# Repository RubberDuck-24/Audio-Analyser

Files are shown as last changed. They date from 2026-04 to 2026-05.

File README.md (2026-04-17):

# Audio-Analyser

PC-controlled audio analyzer with integrated dummy load for objective testing and calibration of audio amplifiers.

## Overview

This project provides a complete measurement chain for testing audio amplifiers — measuring key parameters like THD(+N), frequency response, and noise level. It replaces subjective "does it sound right?" evaluations with quantitative, reproducible, and logged results.

Developed as a bachelor project at Ingeniørhøjskolen, Aarhus University.

## Features

- **FFT-based spectrum analysis** with live updating display
- **THD+N measurement** at 1 kHz (and across frequency)
- **Internal loopback** via integrated DAC → ADC signal path
- **Dummy load** switchable between 4 Ω and 8 Ω, rated for ≥ 200 W
- **Over-temperature protection** with automatic relay cutoff (fail-safe)
- **Data logging** to CSV/JSON with date, DUT ID, load mode and sample rate
- **PDF report generation** with test info, results and FFT plots
- **24-bit / 192 kHz** dual-channel synchronous capture

## System Architecture
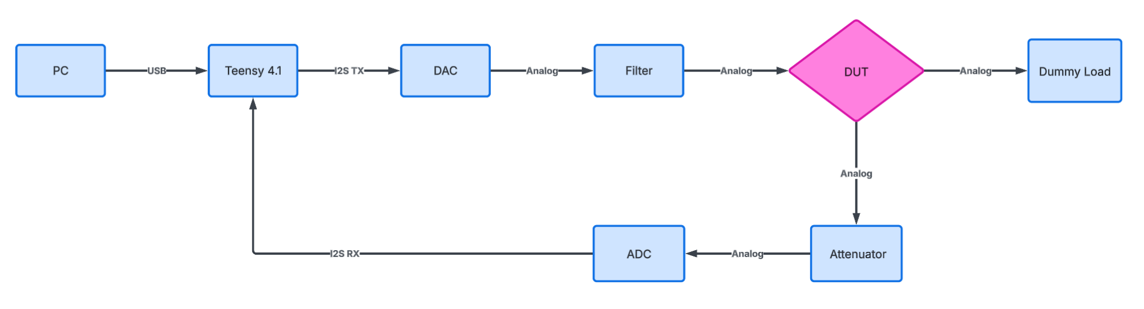
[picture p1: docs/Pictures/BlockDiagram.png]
System Architecture

The signal chain is split into two branches:
- **Generator path**: PC → Teensy → DAC → Filter → DUT
- **Measurement path**: DUT → Attenuator → ADC → Teensy → PC

## Hardware

| Component | Description |
|---|---|
| Teensy 4.1 | MCU — USB High-Speed (480 Mbit/s), hardware I2S TX/RX |
| TI PCM4222EVM | 24-bit, 2-channel delta-sigma ADC |
| Adafruit PCM5102 | 32-bit I2S DAC, line-level output (~2.1 V RMS), no external control bus needed |
| Dummy Load | 16× 2 Ω/100 W resistors, 2-branch per channel configuration, relay-switched 4 Ω / 8 Ω |

## Repository Structure

Audio-Analyser/
- docs: Documentation, reports, measurements and pictures
- firmware: Teensy 4.1 firmware (PlatformIO / Arduino framework)
- software: PC-side Python application (FFT GUI, logging, reporting)

## Measurement Standards

Audio measurements are referenced against **DS/EN IEC 60268-3:2018** — *Sound system equipment, Part 3: Amplifiers* — used as a technical reference for parameters such as THD(+N), frequency response, and load conditions.

## Author

**Christian Rasmussen**

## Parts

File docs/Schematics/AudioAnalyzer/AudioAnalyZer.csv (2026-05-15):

Reference | Qty | Value | DNP | Exclude from BOM | Exclude from Board | Footprint | Datasheet | MANUFACTURER | MAXIMUM_PACKAGE_HEIGHT | MF | MP | PARTREV | Package | Price | Purchase-URL | STANDARD | Sim.Device | Sim.Pins | SnapEDA_Link | VERIFIER
C1,C6,C7,C28,C37,C38,C39,C41,C43,C44,C45,C46,C52,C56,C57,C58,C62,C65,C69,C71,C73,C74,C81,C82,C83,C84,C86 | 27 | 100nF |  |  |  | Capacitor_SMD:C_0603_1608Metric_Pad1.08x0.95mm_HandSolder
C2,C27,C54,C55 | 4 | 22uF |  |  |  | Capacitor_SMD:C_1206_3216Metric
C3,C29 | 2 | 47uF |  |  |  | Capacitor_SMD:CP_Elec_10x10.5
C4,C5,C23,C24 | 4 | 47uF |  |  |  | Capacitor_SMD:CP_Elec_6.3x7.7
C8,C9 | 2 | 10uF |  |  |  | Capacitor_SMD:C_1206_3216Metric
C10 | 1 | 100nF |  |  |  | Capacitor_SMD:C_0805_2012Metric
C11 | 1 | 10uF |  |  |  | Capacitor_SMD:CP_Elec_8x10.5
C12,C18,C19 | 3 | 2.2uF |  |  |  | Capacitor_SMD:C_1210_3225Metric
C14,C21 | 2 | 6800pF |  |  |  | Capacitor_SMD:C_0603_1608Metric_Pad1.08x0.95mm_HandSolder
C15,C22 | 2 | 39pF |  |  |  | Capacitor_SMD:C_0603_1608Metric_Pad1.08x0.95mm_HandSolder
C16,C17 | 2 | 47uF |  |  |  | Capacitor_SMD:C_1210_3225Metric
C20,C30 | 2 | 0.1uF |  |  |  | Capacitor_SMD:C_0603_1608Metric_Pad1.08x0.95mm_HandSolder
C25 | 1 | 2.2uF |  |  |  | Capacitor_SMD:C_1210_3225Metric_Pad1.33x2.70mm_HandSolder
C31 | 1 | 2.7nF |  |  |  | Capacitor_SMD:C_0603_1608Metric
C33,C35,C49,C50 | 4 | 100pF |  |  |  | Capacitor_SMD:C_0603_1608Metric_Pad1.08x0.95mm_HandSolder
C34,C36,C40,C47,C48,C51,C64,C76,C88 | 9 | DNP |  |  |  | Capacitor_SMD:C_0603_1608Metric_Pad1.08x0.95mm_HandSolder
C42,C53 | 2 | 100uF |  |  |  | Capacitor_SMD:C_1210_3225Metric
C59 | 1 | 2.7nF |  |  |  | Capacitor_SMD:C_0603_1608Metric_Pad1.08x0.95mm_HandSolder
C60,C61 | 2 | 2.2nF |  |  |  | Capacitor_SMD:C_0603_1608Metric_Pad1.08x0.95mm_HandSolder
C63,C77,C85,C87 | 4 | 1uF |  |  |  | Capacitor_SMD:C_0603_1608Metric_Pad1.08x0.95mm_HandSolder
C66,C67 | 2 | 2.2uF |  |  |  | Capacitor_SMD:C_1206_3216Metric
C68,C70,C72,C75,C78 | 5 | 10uF |  |  |  | Capacitor_SMD:C_0805_2012Metric
C79,C80 | 2 | 10uF |  |  |  | Capacitor_Tantalum_SMD:CP_EIA-3216-18_Kemet-A
CR1,CR2,CR3,CR4,CR5,CR6,CR7,CR8 | 8 | VS-15MQ040-M3/5AT |  |  |  | VS-15MQ040-M3-5AT:CR_Q040-M3&slash_5AT_VIS | https://www.vishay.com/doc?93366
D1,D2 | 2 | S1G-13-F |  |  |  | Diode_SMD:D_SMA | https://www.diodes.com/assets/Datasheets/ds16008.pdf |  |  |  |  |  |  |  |  |  | D | 1=K 2=A
D3,D5 | 2 | B560C-13-F |  |  |  | Diode_SMD:D_SMC_Handsoldering
D4 | 1 | SMCJ58A-13-F |  |  |  | SMCJ58A-13-F:DIOM7959X250N |  | Diodes Incorporated | 2.5mm | Diodes Inc. | SMCJ58A-13-F | 2-May | DO-214 Diodes Inc. | None | https://www.snapeda.com/api/url_track_click_mouser/?unipart_id=831879&manufacturer=Diodes Inc.&part_name=SMCJ58A-13-F&search_term=smcj58a-13-f | IPC-7351B |  |  | https://www.snapeda.com/parts/SMCJ58A-13-F/Diodes+Inc./view-part/?ref=snap
D6,D7,D8,D9,D10,D11,D12,D13,D14 | 9 | LED |  |  |  | LED_SMD:LED_0603_1608Metric_Pad1.05x0.95mm_HandSolder |  |  |  |  |  |  |  |  |  |  |  | 1=K 2=A
F2 | 1 | Fuse |  |  |  | 0451002:0451Series_LTF-M
FB1,FB2 | 2 | FerriteBead |  |  |  | BLM21PG221SN1D:BEADC2012X105N
J1,J3,J4,J6 | 4 | CONBNC002 |  |  |  | CONBNC002:LINX_CONBNC002 |  |  |  | TE Connectivity | CONBNC002 |  | None | None | https://www.snapeda.com/api/url_track_click_mouser/?unipart_id=10849425&manufacturer=Linx Technologies Inc.&part_name=CONBNC002&search_term=None |  |  |  | https://www.snapeda.com/parts/CONBNC002/TE+Connectivity/view-part/?ref=snap
J2 | 1 | Barrel_Jack |  |  |  | Connector_BarrelJack:BarrelJack_CUI_PJ-063AH_Horizontal
J5 | 1 | DummyLoad |  |  |  | Connector_PinHeader_2.54mm:PinHeader_1x07_P2.54mm_Horizontal
K3,K4,K5,K6,K7,K8,K9,K10 | 8 | Relay_DPDT |  |  |  | IM06DGR:RELAY_IM06DGR
L2,L3,L5,L6 | 4 | 22uH |  |  |  | HCM1A0805V2:IND_HCM1A0805V2_EAT-L
L7 | 1 | 8.2uH |  |  |  | WE-PD_1030P:WE-PD_1030P
OSC1 | 1 | SM7745HEV |  |  |  | SM7745HEV:SM77H_PLT | SM7745HEV-50.0M
Q1,Q2,Q3,Q4,Q5,Q6,Q7,Q8 | 8 | NX3008NBKW |  |  |  | NX3008NBKW:SC-70_SOT323_NEX | NX3008NBKW
R1,R3,R20,R22,R34,R35,R36,R37 | 8 | 33.6k |  |  |  | Resistor_SMD:R_0603_1608Metric_Pad0.98x0.95mm_HandSolder
R2 | 1 | 4.7 |  |  |  | Resistor_SMD:R_1206_3216Metric_Pad1.30x1.75mm_HandSolder
R4,R10 | 2 | 84.5 |  |  |  | Resistor_SMD:R_0603_1608Metric_Pad0.98x0.95mm_HandSolder
R5,R9 | 2 | 523k |  |  |  | Resistor_SMD:R_0805_2012Metric_Pad1.20x1.40mm_HandSolder
R6,R12 | 2 | 13k |  |  |  | Resistor_SMD:R_0603_1608Metric_Pad0.98x0.95mm_HandSolder
R7 | 1 | 53.6k |  |  |  | Resistor_SMD:R_0603_1608Metric_Pad0.98x0.95mm_HandSolder
R8,R14 | 2 | 10.2k |  |  |  | Resistor_SMD:R_0603_1608Metric_Pad0.98x0.95mm_HandSolder
R11,R19 | 2 | 162k |  |  |  | Resistor_SMD:R_0603_1608Metric_Pad0.98x0.95mm_HandSolder
R13 | 1 | 143k |  |  |  | Resistor_SMD:R_0603_1608Metric_Pad0.98x0.95mm_HandSolder
R15,R16,R43,R44 | 4 | 40.2 |  |  |  | Resistor_SMD:R_0603_1608Metric_Pad0.98x0.95mm_HandSolder
R17,R18,R45,R46,R77 | 5 | 0 |  |  |  | Resistor_SMD:R_0603_1608Metric_Pad0.98x0.95mm_HandSolder
R21 | 1 | 0/DNP |  |  |  | Resistor_SMD:R_0603_1608Metric_Pad0.98x0.95mm_HandSolder
R23,R24,R38,R39 | 4 | 16.8k |  |  |  | Resistor_SMD:R_0603_1608Metric_Pad0.98x0.95mm_HandSolder
R25,R26,R41,R42 | 4 | 2.7k |  |  |  | Resistor_SMD:R_0603_1608Metric_Pad0.98x0.95mm_HandSolder
R27,R28,R29,R31,R32,R33,R47,R49,R50,R51,R52,R53,R54,R55,R56,R57,R58,R59,R60,R61,R62,R63,R67,R70,R78,R79,R82,R83 | 28 | 10k |  |  |  | Resistor_SMD:R_0603_1608Metric_Pad0.98x0.95mm_HandSolder
R30,R40 | 2 | 1k |  |  |  | Resistor_SMD:R_0603_1608Metric_Pad0.98x0.95mm_HandSolder
R48 | 1 | 33 |  |  |  | Resistor_SMD:R_0603_1608Metric_Pad0.98x0.95mm_HandSolder
R64,R65 | 2 | 470 |  |  |  | Resistor_SMD:R_0603_1608Metric_Pad0.98x0.95mm_HandSolder
R66,R69,R80,R81 | 4 | 100 |  |  |  | Resistor_SMD:R_0603_1608Metric_Pad0.98x0.95mm_HandSolder
R68 | 1 | 0 |  |  |  | Resistor_SMD:R_1206_3216Metric_Pad1.30x1.75mm_HandSolder
R71,R72,R73 | 3 | 47 |  |  |  | Resistor_SMD:R_0603_1608Metric_Pad0.98x0.95mm_HandSolder
R74 | 1 | 240 |  |  |  | Resistor_SMD:R_0603_1608Metric_Pad0.98x0.95mm_HandSolder
R75 | 1 | 200 |  |  |  | Resistor_SMD:R_0603_1608Metric_Pad0.98x0.95mm_HandSolder
R76 | 1 | 324 |  |  |  | Resistor_SMD:R_0603_1608Metric_Pad0.98x0.95mm_HandSolder
R84 | 1 | 100k |  |  |  | Resistor_SMD:R_1206_3216Metric_Pad1.30x1.75mm_HandSolder
R85 | 1 | 5.6k |  |  |  | Resistor_SMD:R_0603_1608Metric_Pad0.98x0.95mm_HandSolder
R86 | 1 | 20k |  |  |  | Resistor_SMD:R_0603_1608Metric_Pad0.98x0.95mm_HandSolder
R87 | 1 | 3.9k |  |  |  | Resistor_SMD:R_0603_1608Metric_Pad0.98x0.95mm_HandSolder
R88,R91 | 2 | 2.4k |  |  |  | Resistor_SMD:R_0603_1608Metric_Pad0.98x0.95mm_HandSolder
R89,R90 | 2 | 27k |  |  |  | Resistor_SMD:R_0603_1608Metric_Pad0.98x0.95mm_HandSolder
R92 | 1 | 2.2k |  |  |  | Resistor_SMD:R_0603_1608Metric_Pad0.98x0.95mm_HandSolder
RN3 | 1 | 100 |  |  |  | EXB-38V103JV:RESCAXS80P320X160X60-8N
S1 | 1 | B3F-1000 |  |  |  | B3F-1000:SW_B3F-1000 |  |  |  | Omron | B3F1000 |  | None | None |  |  |  |  | https://www.snapeda.com/parts/B3F1000/Omron/view-part/?ref=snap
U1 | 1 | PCM4222PFBR |  |  |  | PCM4222PFBR:PFB48-M | https://www.ti.com/lit/gpn/pcm4222
U2 | 1 | PCM5102A |  |  |  | Package_SO:TSSOP-20_4.4x6.5mm_P0.65mm | https://www.ti.com/lit/ds/symlink/pcm5102a.pdf
U3 | 1 | DEV-16771 |  |  |  | DEV-16771:MODULE_DEV-16771 |  | SparkFun Electronics | 4.07mm | SparkFun Electronics | DEV-16771 | 4.1 | None | None |  | Manufacturer recommendations |  |  | https://www.snapeda.com/parts/DEV-16771/SparkFun/view-part/?ref=snap
U4,U7 | 2 | OPA1632D |  |  |  | OPA1632D:SOIC127P599X175-8N |  |  |  | Texas Instruments | OPA1632D |  | SOIC-8 Texas Instruments | None |  |  |  |  | https://www.snapeda.com/parts/OPA1632D/Texas+Instruments/view-part/?ref=snap
U5,U6 | 2 | OPA277UA |  |  |  | OPA277UA:SOIC127P599X175-8N |  | Texas Instruments | 1.75 mm | Texas Instruments | OPA277UA | Feb-19 | SOIC-8 Texas Instruments | None |  | IPC 7351B |  |  | https://www.snapeda.com/parts/OPA277UA/Texas+Instruments/view-part/?ref=snap
U8,U11 | 2 | TPS54360BDDAR |  |  |  | TPS54360BDDAR:U_DDA_TEX-M | https://www.ti.com/lit/gpn/tps54360b
U9 | 1 | REG1117-3.3G4 |  |  |  | REG1117-3.3G4:SOT230P700X180-4N |  |  |  | Texas Instruments | REG1117-3.3G4 |  | SOT-223-4 Texas Instruments | None |  |  |  |  | https://www.snapeda.com/parts/REG1117-3.3G4/Texas+Instruments/view-part/?ref=snap
U10 | 1 | LM317_TO-252 |  |  |  | Package_TO_SOT_SMD:TO-252-2 | http://www.ti.com/lit/ds/snvs774n/snvs774n.pdf
U12 | 1 | ADR4525BRZ |  |  |  | ADR4525BRZ:SOIC127P600X175-8N |  | Analog Devices | 1.75mm | Analog Devices | ADR4525BRZ | G | SOIC-8 Analog Devices | None |  | IPC-7351B |  |  | https://www.snapeda.com/parts/ADR4525BRZ/Analog+Devices/view-part/?ref=snap
U13 | 1 | DKA15C-15 |  |  |  | DKA15C:DKA15C

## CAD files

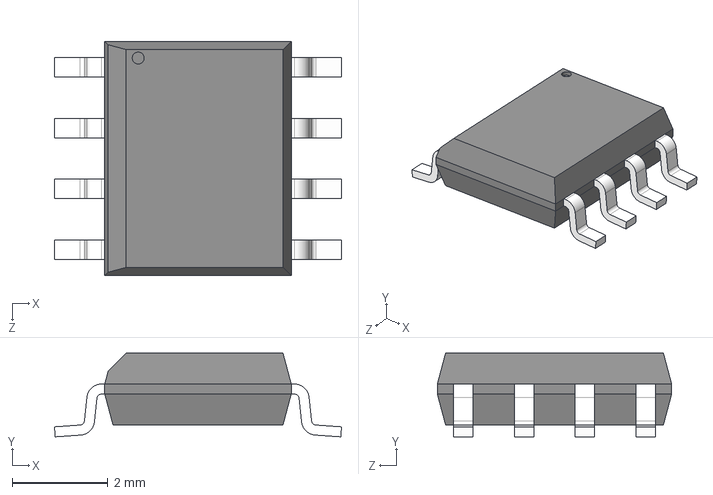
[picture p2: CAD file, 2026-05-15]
docs/Parts/ADR4525BRZ/ADR4525BRZ.step
6.00 x 1.75 x 4.90 mm

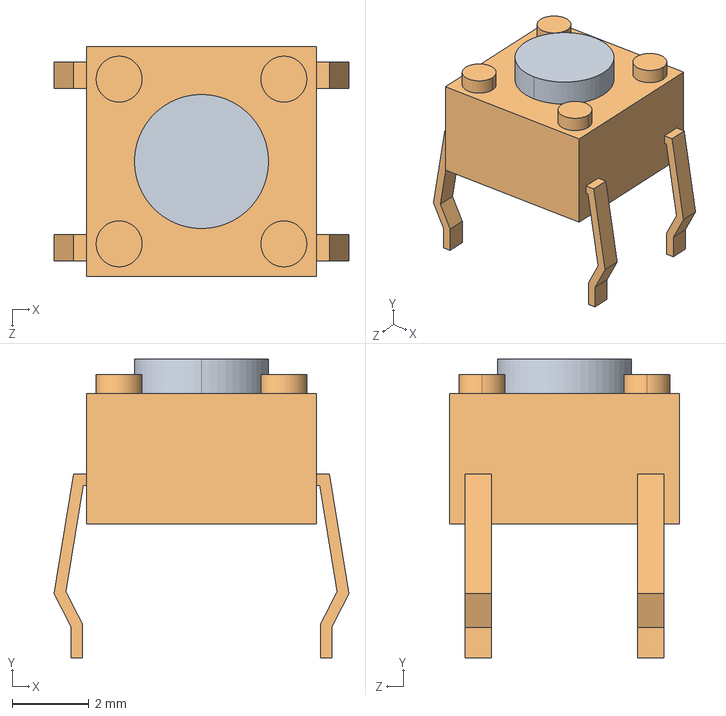
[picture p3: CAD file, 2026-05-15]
docs/Parts/B3F-1000/B3F-1000.step
7.70 x 7.80 x 6.00 mm
B3F_1000_BUTTON
B3F_1000_BASE

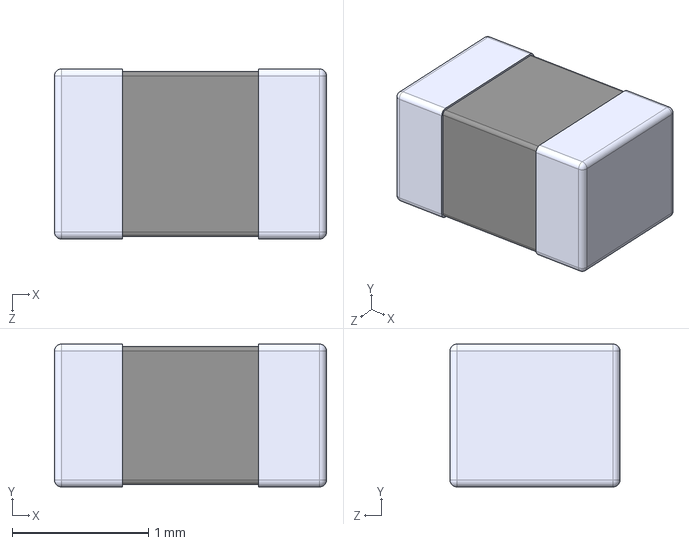
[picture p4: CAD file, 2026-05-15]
docs/Parts/BLM21PG221SN1D/BLM21PG221SN1D.step
2.00 x 1.05 x 1.25 mm

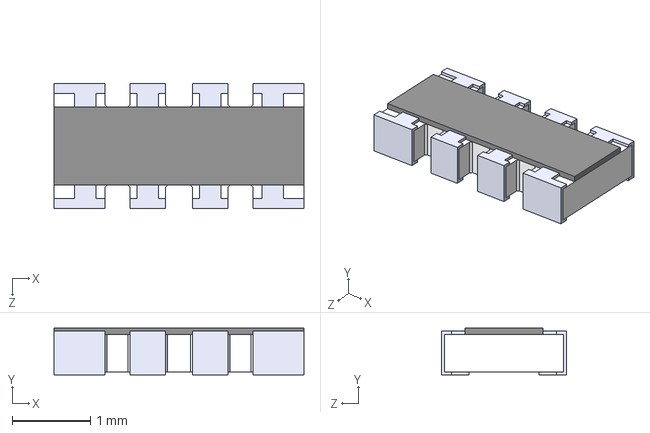
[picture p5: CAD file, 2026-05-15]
docs/Parts/EXB-38V103JV/EXB-38V103JV.step
3.20 x 0.6 x 1.60 mm

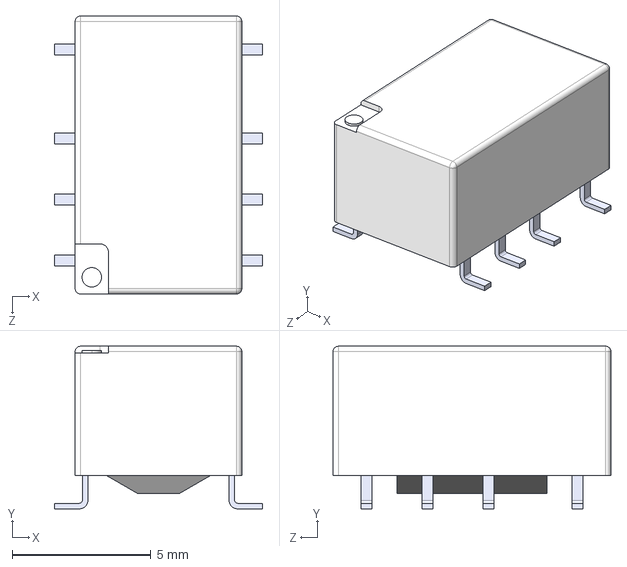
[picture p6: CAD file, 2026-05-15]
docs/Parts/IM06DGR/IM06DGR.step
7.50 x 5.85 x 10.0 mm

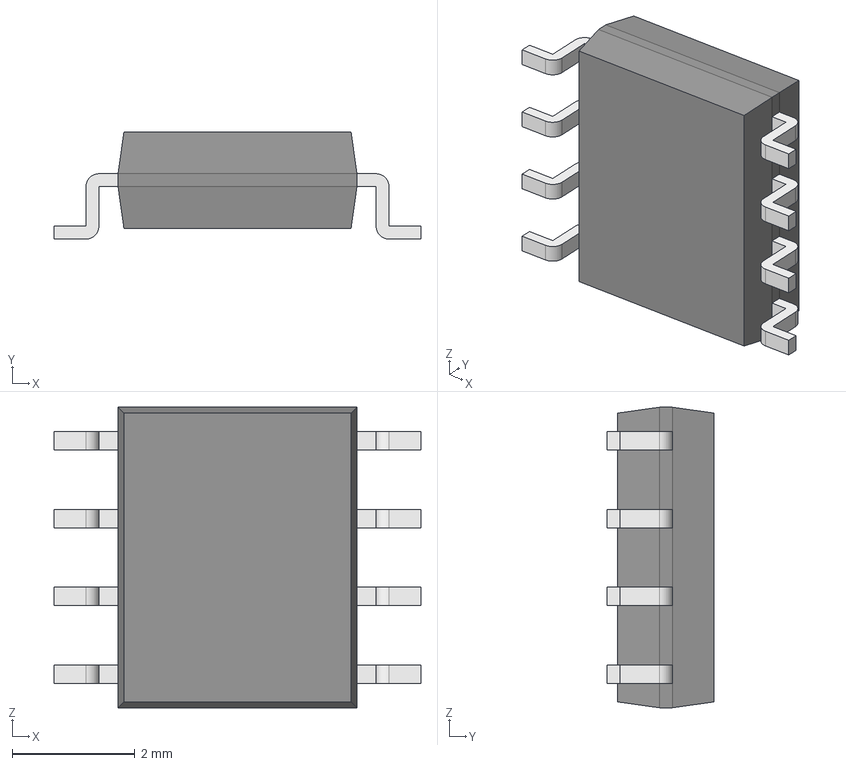
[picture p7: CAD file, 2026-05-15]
docs/Parts/OPA1632D/OPA1632D.step
5.99 x 1.75 x 4.91 mm
Body001 (Mirror #1) x 4
XY-plane x 12
X-axis x 12

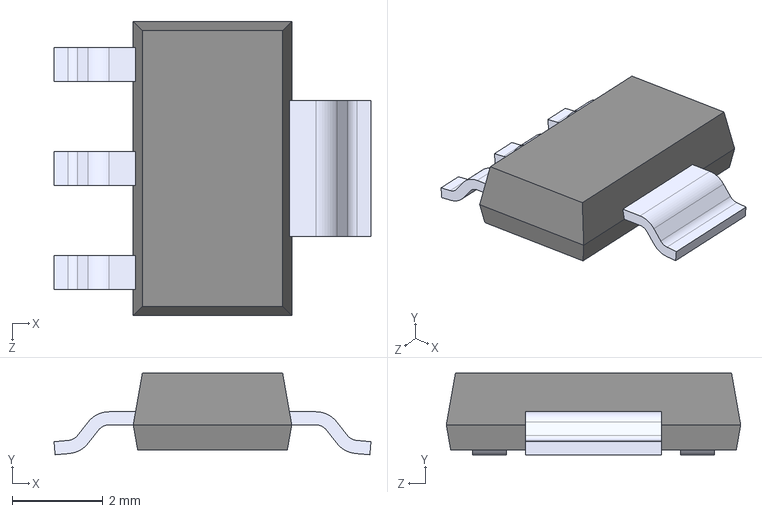
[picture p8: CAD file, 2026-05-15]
docs/Parts/REG1117-3.3G4/REG1117-3.3G4.step
7.00 x 1.80 x 6.50 mm

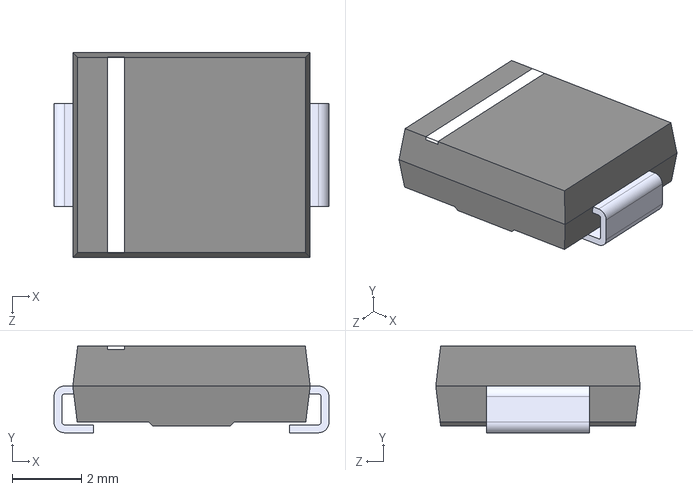
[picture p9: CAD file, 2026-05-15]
docs/Parts/SMCJ58A-13-F/SMCJ58A-13-F.step
7.94 x 2.50 x 5.91 mm

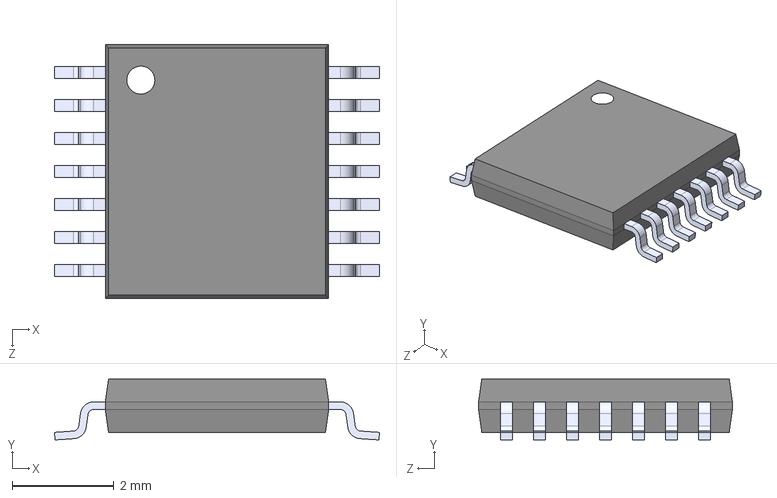
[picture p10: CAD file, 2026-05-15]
docs/Parts/SN74LVC74APW/SN74LVC74APW.step
6.40 x 1.20 x 5.00 mm

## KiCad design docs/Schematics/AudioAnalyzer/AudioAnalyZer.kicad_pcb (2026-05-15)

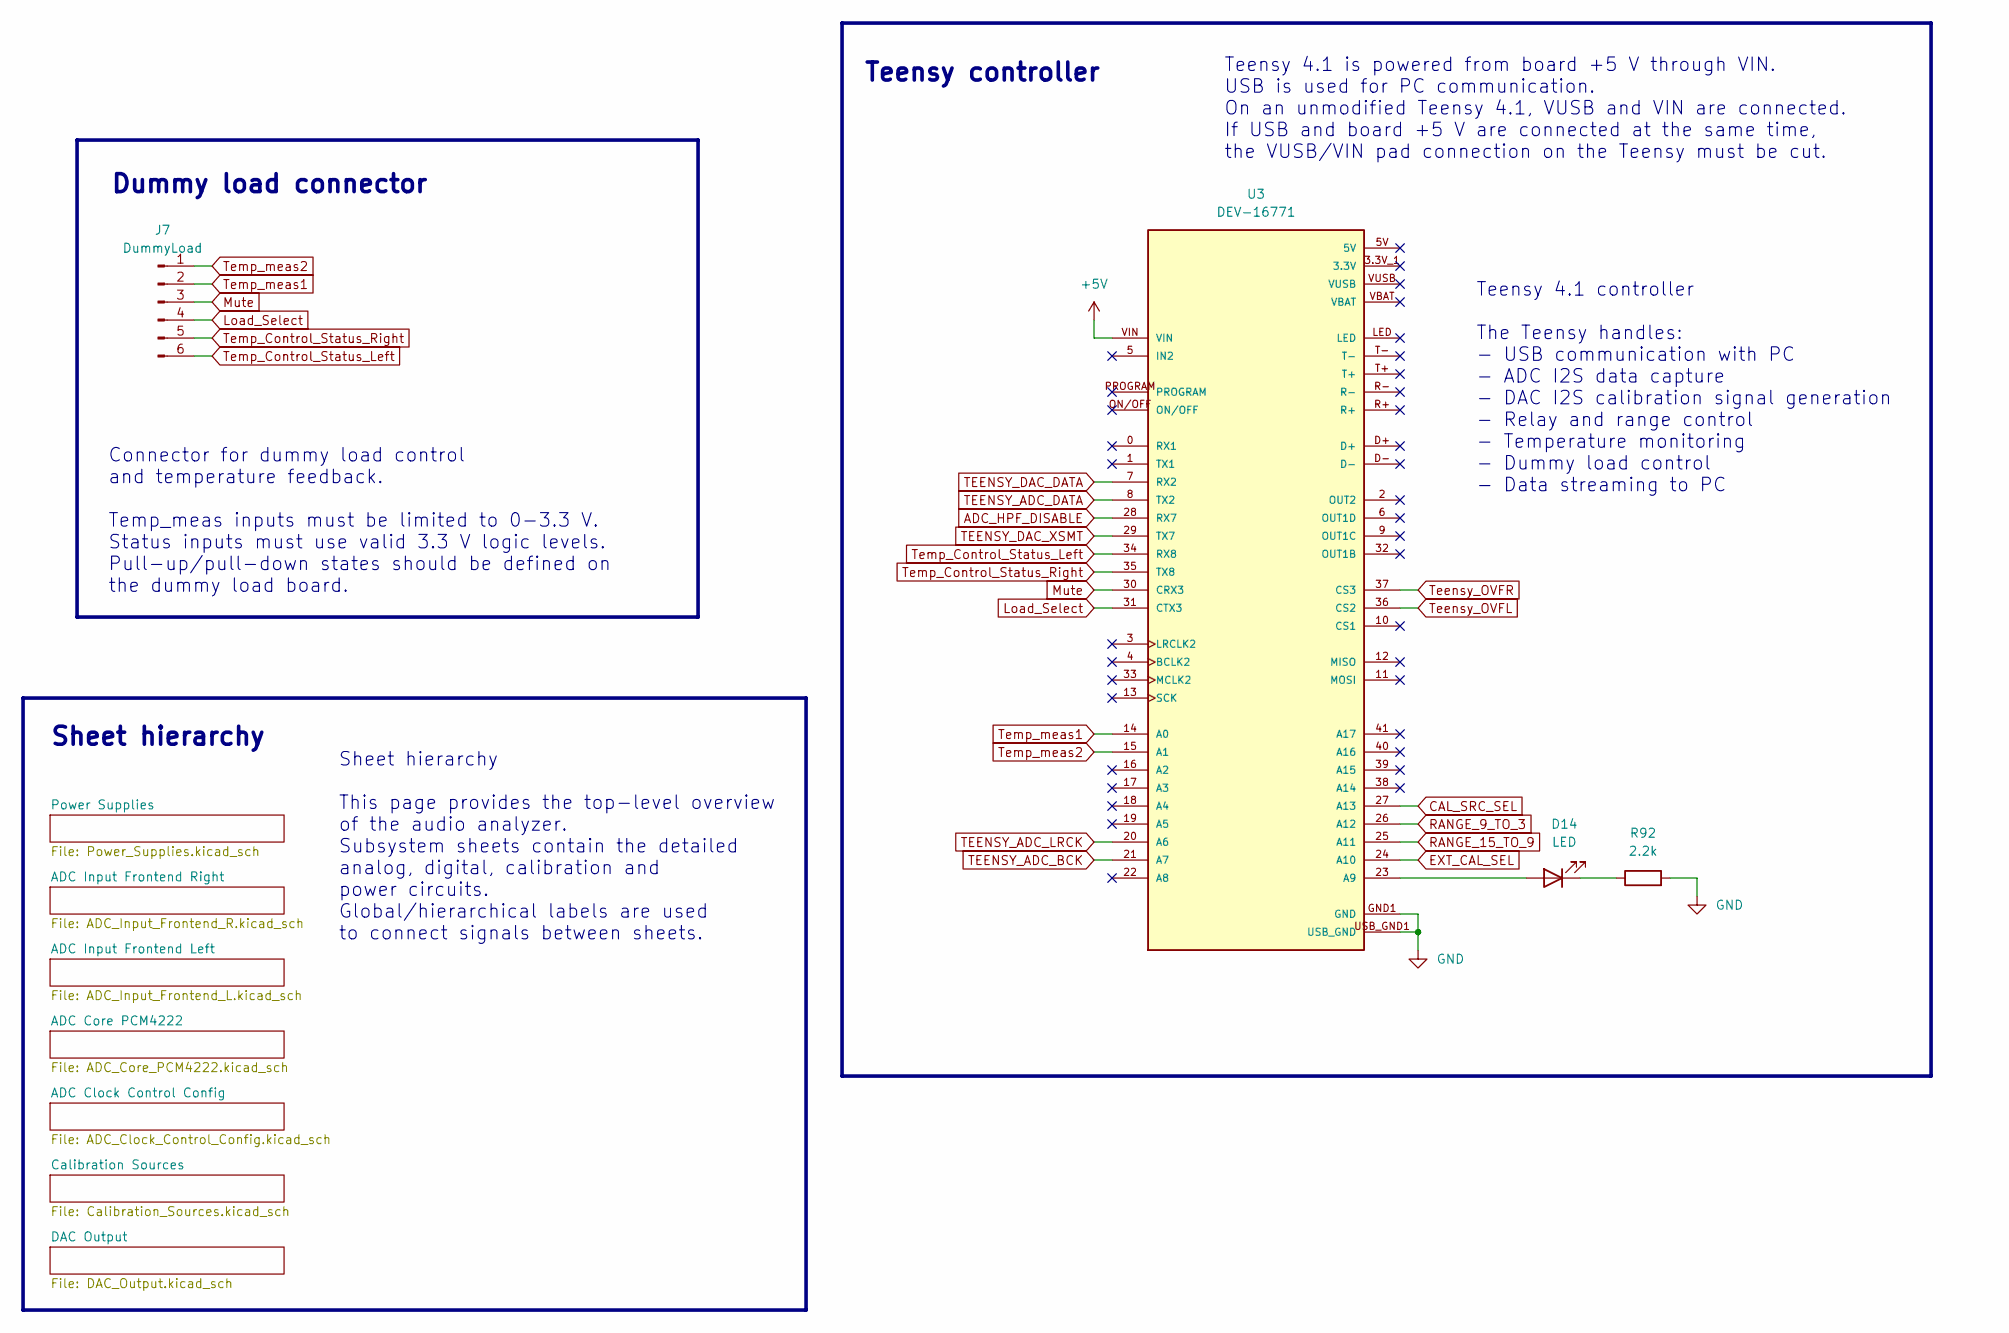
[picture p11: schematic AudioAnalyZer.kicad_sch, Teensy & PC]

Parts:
D14: LED; LED_0603_1608Metric_Pad1.05x0.95mm_HandSolder
J7: DummyLoad; PinHeader_1x06_P2.54mm_Horizontal
R92: 2.2k; R_0603_1608Metric_Pad0.98x0.95mm_HandSolder
U3: DEV-16771; MODULE_DEV-16771; PARTREV 4.1

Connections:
+5V: U3.VIN; also elsewhere on the board
ADC_HPF_DISABLE: U3.28 (RX7); also elsewhere on the board
CAL_SRC_SEL: U3.27 (A13); also elsewhere on the board
EXT_CAL_SEL: U3.24 (A10); also elsewhere on the board
GND: R92.2, U3.GND1 (GND), U3.GND2 (GND), U3.GND3 (GND), U3.GND4 (GND), U3.GND5 (GND), U3.USB_GND1 (USB_GND), U3.USB_GND2 (USB_GND); also elsewhere on the board
Load_Select: J7.4, U3.31 (CTX3)
Mute: J7.3, U3.30 (CRX3)
unnamed: D14.2 (A), U3.23 (A9)
unnamed: D14.1 (K), R92.1
RANGE_9_TO_3: U3.26 (A12); also elsewhere on the board
RANGE_15_TO_9: U3.25 (A11); also elsewhere on the board
TEENSY_ADC_BCK: U3.21 (A7); also elsewhere on the board
TEENSY_ADC_DATA: U3.8 (TX2); also elsewhere on the board
TEENSY_ADC_LRCK: U3.20 (A6); also elsewhere on the board
TEENSY_DAC_DATA: U3.7 (RX2); also elsewhere on the board
TEENSY_DAC_XSMT: U3.29 (TX7); also elsewhere on the board
Teensy_OVFL: U3.36 (CS2); also elsewhere on the board
Teensy_OVFR: U3.37 (CS3); also elsewhere on the board
Temp_Control_Status_Left: J7.6, U3.34 (RX8)
Temp_Control_Status_Right: J7.5, U3.35 (TX8)
Temp_meas1: J7.2, U3.14 (A0)
Temp_meas2: J7.1, U3.15 (A1)

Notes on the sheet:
Teensy controller
Teensy 4.1 controller The Teensy handles: - USB communication with PC - ADC I2S data capture - DAC I2S calibration signal generation - Relay and range control - Temperature monitoring - Dummy load control - Data streaming to PC
Teensy 4.1 is powered from board +5 V through VIN. USB is used for PC communication. On an unmodified Teensy 4.1, VUSB and VIN are connected. If USB and board +5 V are connected at the same time, the VUSB/VIN pad connection on the Teensy must be cut.
Sheet hierarchy This page provides the top-level overview of the audio analyzer. Subsystem sheets contain the detailed analog, digital, calibration and power circuits. Global/hierarchical labels are used to connect signals between sheets.
Connector for dummy load control and temperature feedback. Temp_meas inputs must be limited to 0-3.3 V. Status inputs must use valid 3.3 V logic levels. Pull-up/pull-down states should be defined on the dummy load board.
Dummy load connector
Sheet hierarchy

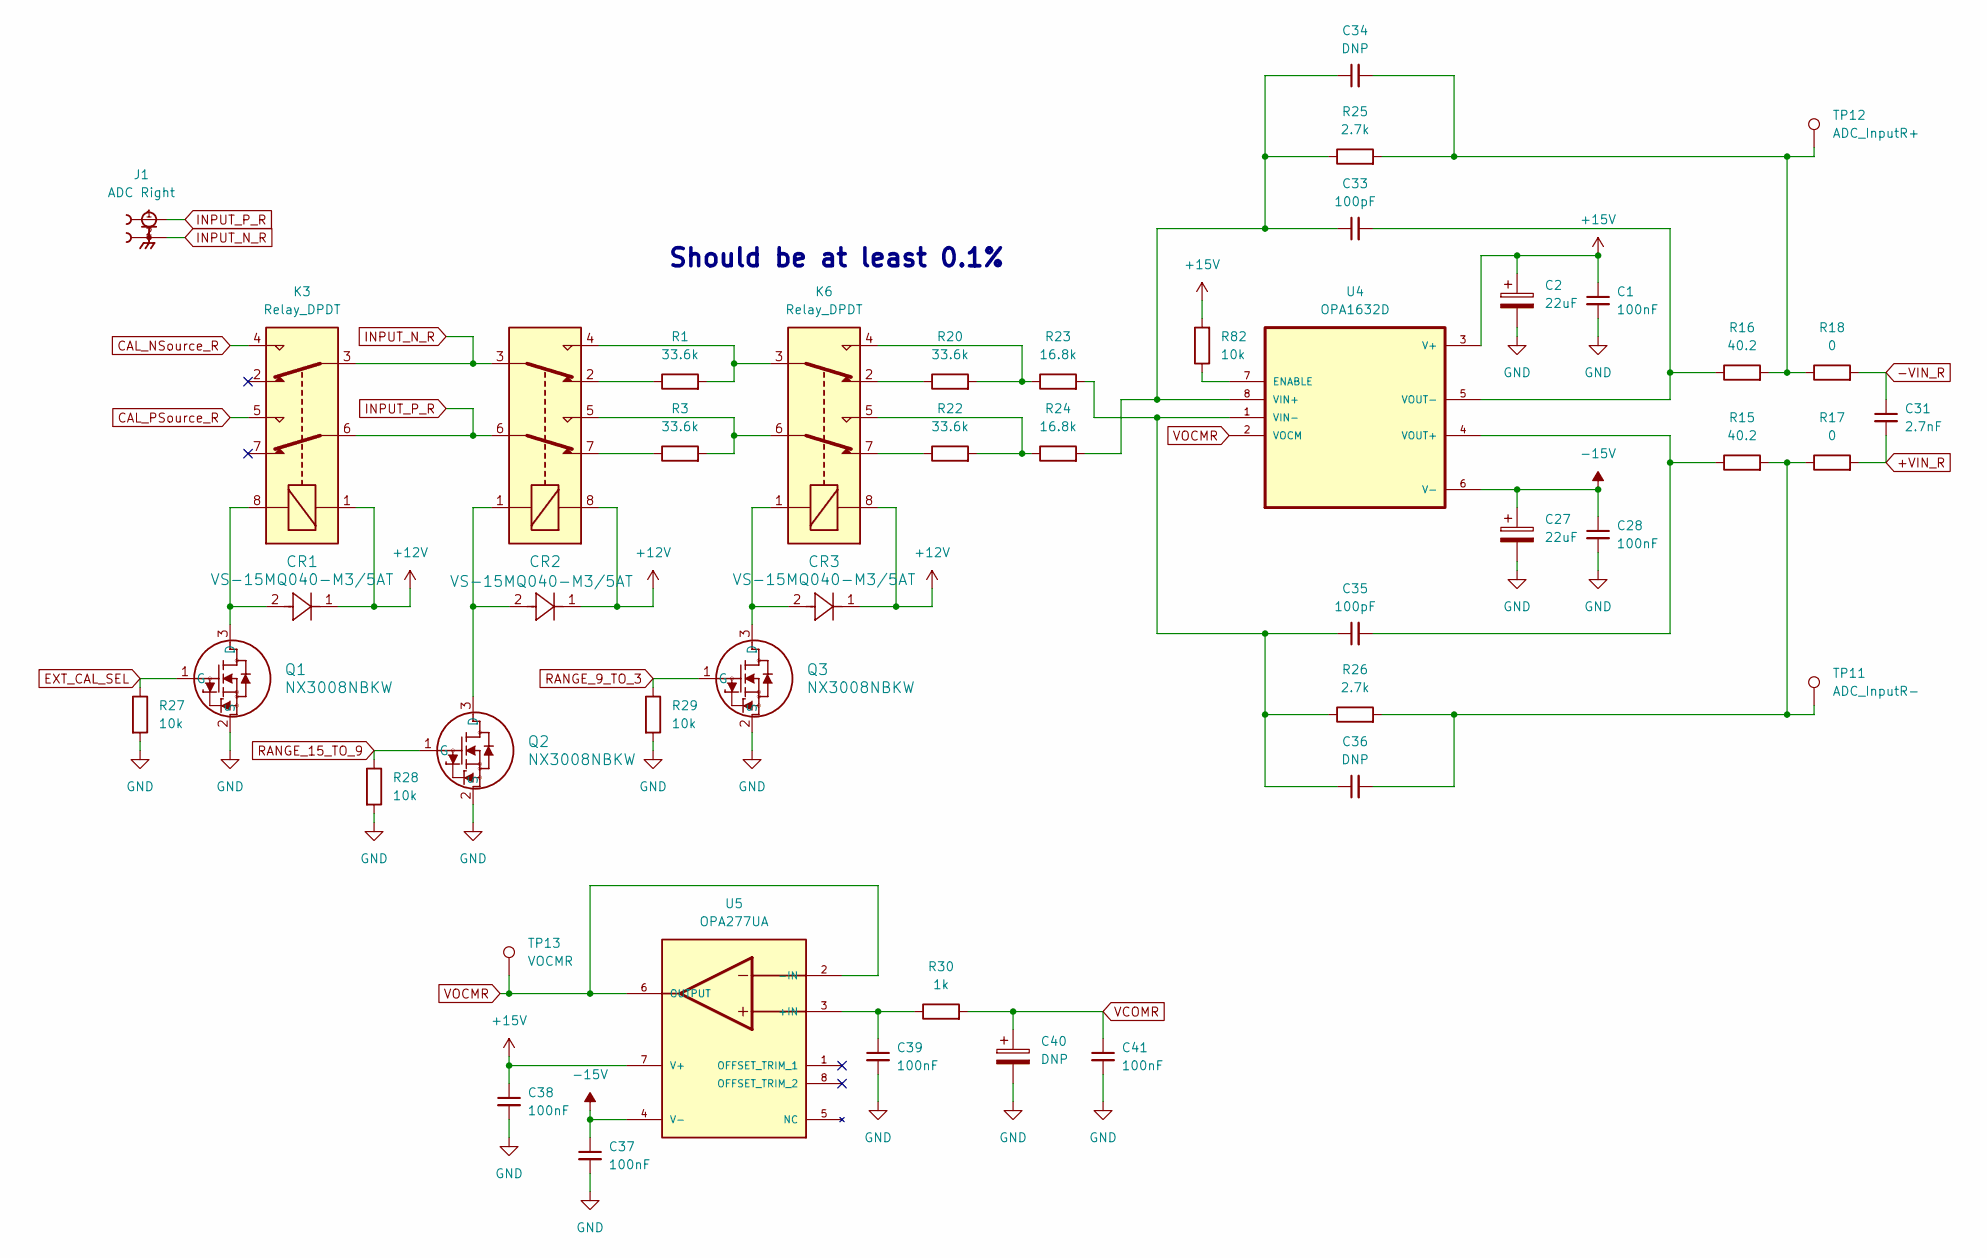
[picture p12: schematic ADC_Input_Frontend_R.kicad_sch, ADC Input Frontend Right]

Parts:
C1, C28, C37, C38, C39, C41: 100nF; C_0603_1608Metric_Pad1.08x0.95mm_HandSolder
C2, C27: 22uF; C_1206_3216Metric
C31: 2.7nF; C_0603_1608Metric
C33, C35: 100pF; C_0603_1608Metric_Pad1.08x0.95mm_HandSolder
C34, C36, C40: DNP; C_0603_1608Metric_Pad1.08x0.95mm_HandSolder
CR1, CR2, CR3: VS-15MQ040-M3/5AT; CR_Q040-M3&slash_5AT_VIS
J1: ADC Right; LINX_CONBNC002
K3, K5, K6: Relay_DPDT; RELAY_IM06DGR
Q1, Q2, Q3: NX3008NBKW; SC-70_SOT323_NEX
R1, R3, R20, R22: 33.6k; R_0603_1608Metric_Pad0.98x0.95mm_HandSolder
R15, R16: 40.2; R_0603_1608Metric_Pad0.98x0.95mm_HandSolder
R17, R18: 0; R_0603_1608Metric_Pad0.98x0.95mm_HandSolder
R23, R24: 16.8k; R_0603_1608Metric_Pad0.98x0.95mm_HandSolder
R25, R26: 2.7k; R_0603_1608Metric_Pad0.98x0.95mm_HandSolder
R27, R28, R29, R82: 10k; R_0603_1608Metric_Pad0.98x0.95mm_HandSolder
R30: 1k; R_0603_1608Metric_Pad0.98x0.95mm_HandSolder
TP11: ADC_InputR-; TestPoint_Pad_D1.5mm
TP12: ADC_InputR+; TestPoint_Pad_D1.5mm
TP13: VOCMR; TestPoint_Pad_D1.5mm
U4: OPA1632D; SOIC127P599X175-8N
U5: OPA277UA; SOIC127P599X175-8N; PARTREV 02/2019

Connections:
+12V: CR1.1, CR2.1, CR3.1, K3.1, K5.8, K6.8; also elsewhere on the board
+15V: C1.1, C2.1, C38.1, R82.2, U4.3 (V+), U5.7 (V+); also elsewhere on the board
+VIN_R: C31.2, R17.2; also elsewhere on the board
-15V: C27.1, C28.1, C37.1, U4.6 (V-), U5.4 (V-); also elsewhere on the board
-VIN_R: C31.1, R18.2; also elsewhere on the board
CAL_NSource_R: K3.4; also elsewhere on the board
CAL_PSource_R: K3.5; also elsewhere on the board
EXT_CAL_SEL: Q1.1 (G), R27.1; also elsewhere on the board
GND: C1.2, C2.2, C27.2, C28.2, C37.2, C38.2, C39.2, C40.2, C41.2, Q1.2 (S), Q2.2 (S), Q3.2 (S), R27.2, R28.2, R29.2; also elsewhere on the board
INPUT_N_R: J1.2, J1.S1, J1.S2, K3.3, K5.3
INPUT_P_R: J1.1, K3.6, K5.6
unnamed: C34.2, R16.2, R18.1, R25.2, TP12.1 (1_1)
unnamed: C36.2, R15.2, R17.1, R26.2, TP11.1 (1_1)
unnamed: K5.2, R1.1
unnamed: K5.4, K6.3, R1.2
unnamed: K5.5, K6.6, R3.2
unnamed: K5.7, R3.1
unnamed: K6.2, R20.1
unnamed: K6.4, R20.2, R23.1
unnamed: K6.5, R22.2, R24.1
unnamed: K6.7, R22.1
unnamed: CR1.2, K3.8, Q1.3 (D)
unnamed: CR2.2, K5.1, Q2.3 (D)
unnamed: CR3.2, K6.1, Q3.3 (D)
unnamed: R82.1, U4.7 (ENABLE)
unnamed: C33.1, C34.1, R24.2, R25.1, U4.8 (VIN+)
unnamed: C35.1, C36.1, R23.2, R26.1, U4.1 (VIN-)
unnamed: C35.2, R15.1, U4.4 (VOUT+)
unnamed: C33.2, R16.1, U4.5 (VOUT-)
unnamed: C39.1, R30.1, U5.3 (+IN)
RANGE_9_TO_3: Q3.1 (G), R29.1; also elsewhere on the board
RANGE_15_TO_9: Q2.1 (G), R28.1; also elsewhere on the board
VCOMR: C40.1, C41.1, R30.2; also elsewhere on the board
VOCMR: TP13.1 (1_1), U4.2 (VOCM), U5.2 (-IN), U5.6 (OUTPUT)

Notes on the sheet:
Should be at least 0.1%

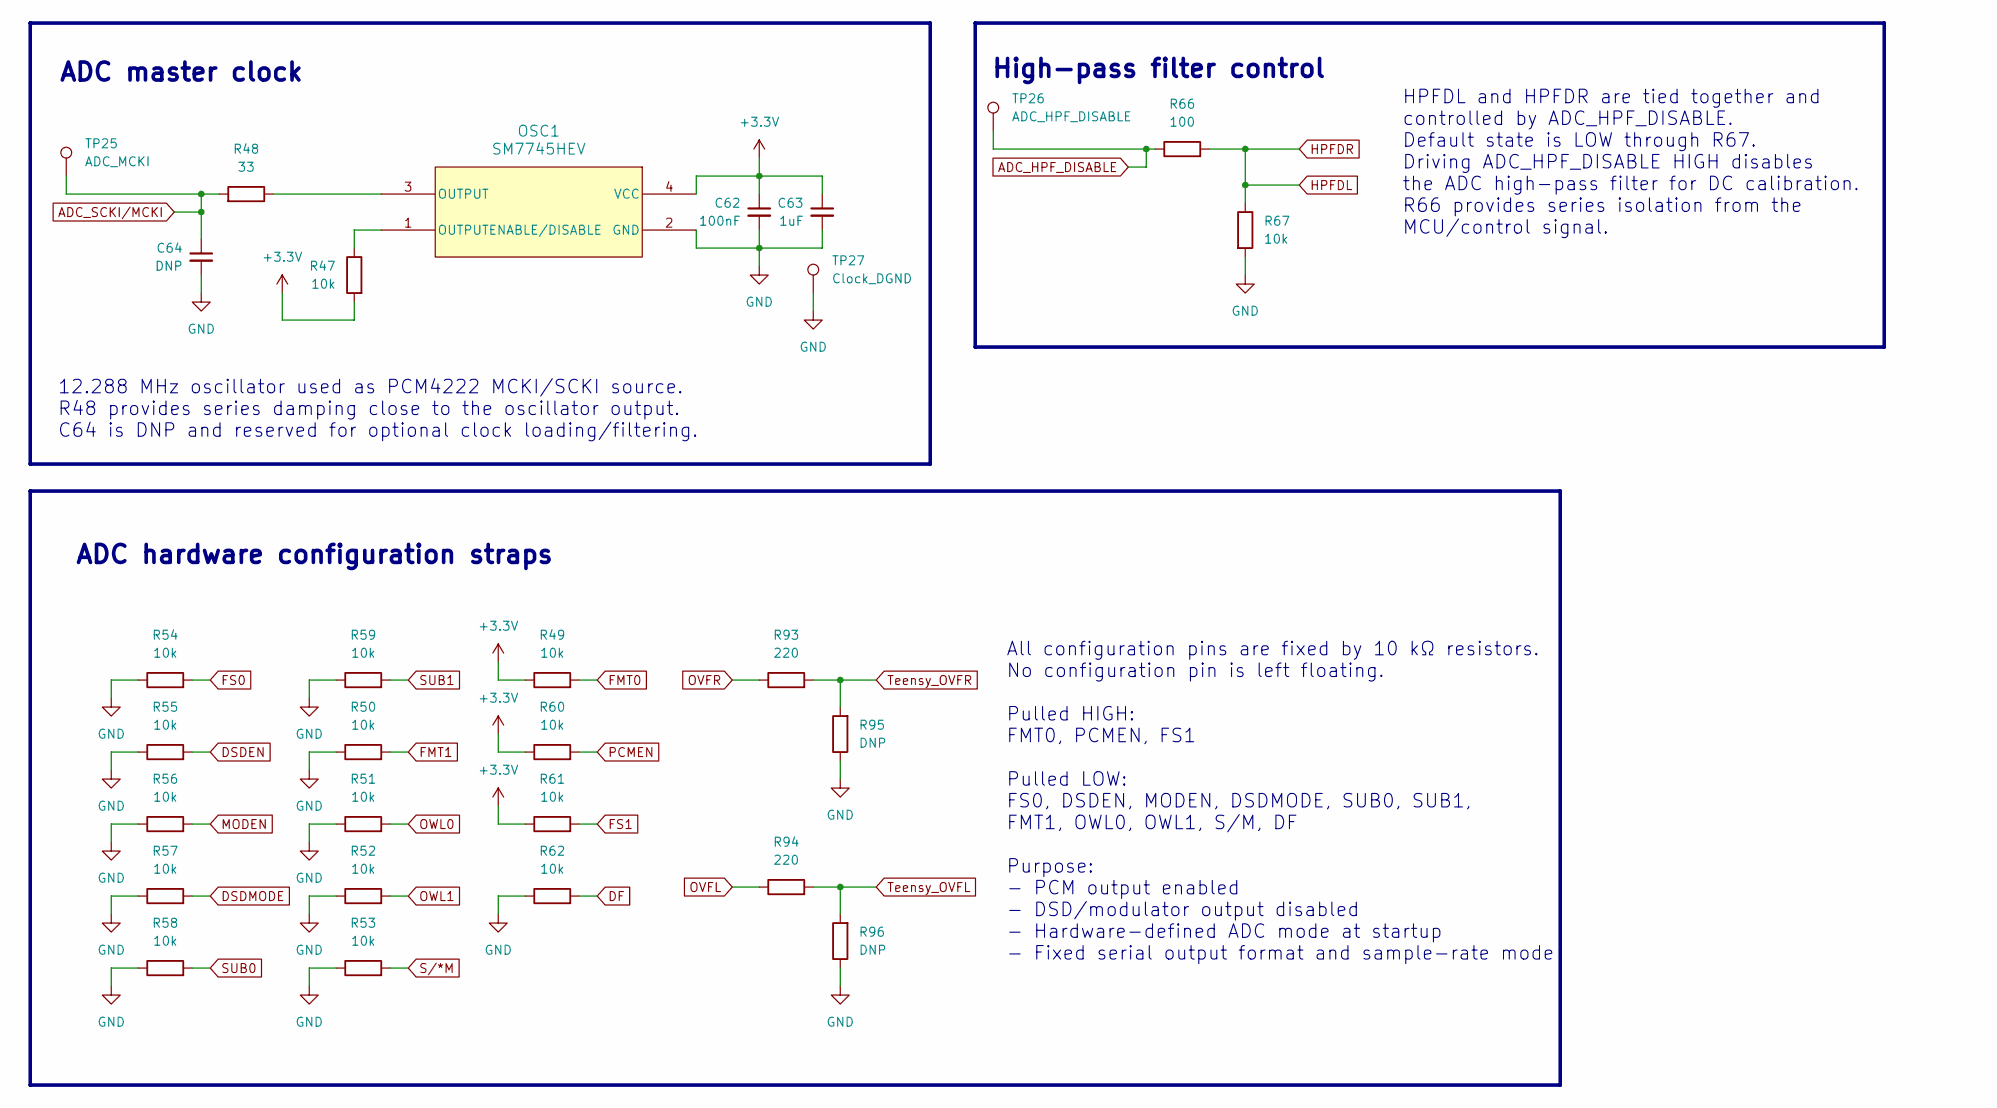
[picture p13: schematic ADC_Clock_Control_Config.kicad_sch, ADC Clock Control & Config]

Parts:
C62: 100nF; C_0603_1608Metric_Pad1.08x0.95mm_HandSolder
C63: 1uF; C_0603_1608Metric_Pad1.08x0.95mm_HandSolder
C64: DNP; C_0603_1608Metric_Pad1.08x0.95mm_HandSolder
OSC1: SM7745HEV; SM77H_PLT
R47, R49, R50, R51, R52, R53, R54, R55, R56, R57, R58, R59, R60, R61, R62, R67: 10k; R_0603_1608Metric_Pad0.98x0.95mm_HandSolder
R48: 33; R_0603_1608Metric_Pad0.98x0.95mm_HandSolder
R66: 100; R_0603_1608Metric_Pad0.98x0.95mm_HandSolder
R93, R94: 220; R_0603_1608Metric_Pad0.98x0.95mm_HandSolder
R95, R96: DNP; R_0603_1608Metric_Pad0.98x0.95mm_HandSolder
TP25: ADC_MCKI; TestPoint_Pad_D1.5mm
TP26: ADC_HPF_DISABLE; TestPoint_Pad_D1.5mm
TP27: Clock_DGND; TestPoint_Pad_D1.5mm

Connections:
+3.3V: C62.1, C63.1, OSC1.4 (VCC), R47.2, R49.1, R60.1, R61.1; also elsewhere on the board
ADC_HPF_DISABLE: R66.1, TP26.1 (1_1); also elsewhere on the board
ADC_SCKI/MCKI: C64.1, R48.2, TP25.1 (1_1); also elsewhere on the board
DF: R62.2; also elsewhere on the board
DSDEN: R55.2; also elsewhere on the board
DSDMODE: R57.2; also elsewhere on the board
FMT0: R49.2; also elsewhere on the board
FMT1: R50.2; also elsewhere on the board
FS0: R54.2; also elsewhere on the board
FS1: R61.2; also elsewhere on the board
GND: C62.2, C63.2, C64.2, OSC1.2 (GND), R50.1, R51.1, R52.1, R53.1, R54.1, R55.1, R56.1, R57.1, R58.1, R59.1, R62.1, R67.2, R95.1, R96.1, TP27.1 (1_1); also elsewhere on the board
HPFDL: R66.2, R67.1; also elsewhere on the board
MODEN: R56.2; also elsewhere on the board
unnamed: OSC1.3 (OUTPUT), R48.1
unnamed: OSC1.1 (OUTPUTENABLE/DISABLE), R47.1
OVFL: R94.1; also elsewhere on the board
OVFR: R93.1; also elsewhere on the board
OWL0: R51.2; also elsewhere on the board
OWL1: R52.2; also elsewhere on the board
PCMEN: R60.2; also elsewhere on the board
SUB0: R58.2; also elsewhere on the board
SUB1: R59.2; also elsewhere on the board
S/*M: R53.2; also elsewhere on the board
Teensy_OVFL: R94.2, R96.2; also elsewhere on the board
Teensy_OVFR: R93.2, R95.2; also elsewhere on the board

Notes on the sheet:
All configuration pins are fixed by 10 kΩ resistors. No configuration pin is left floating. Pulled HIGH: FMT0, PCMEN, FS1 Pulled LOW: FS0, DSDEN, MODEN, DSDMODE, SUB0, SUB1, FMT1, OWL0, OWL1, S/M, DF Purpose: - PCM output enabled - DSD/modulator output disabled - Hardware-defined ADC mode at startu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
ADC master clock
12.288 MHz oscillator used as PCM4222 MCKI/SCKI source. R48 provides series damping close to the oscillator output. C64 is DNP and reserved for optional clock loading/filtering.
ADC hardware configuration straps
High-pass filter control
HPFDL and HPFDR are tied together and controlled by ADC_HPF_DISABLE. Default state is LOW through R67. Driving ADC_HPF_DISABLE HIGH disables the ADC high-pass filter for DC calibration. R66 provides series isolation from the MCU/control signal.

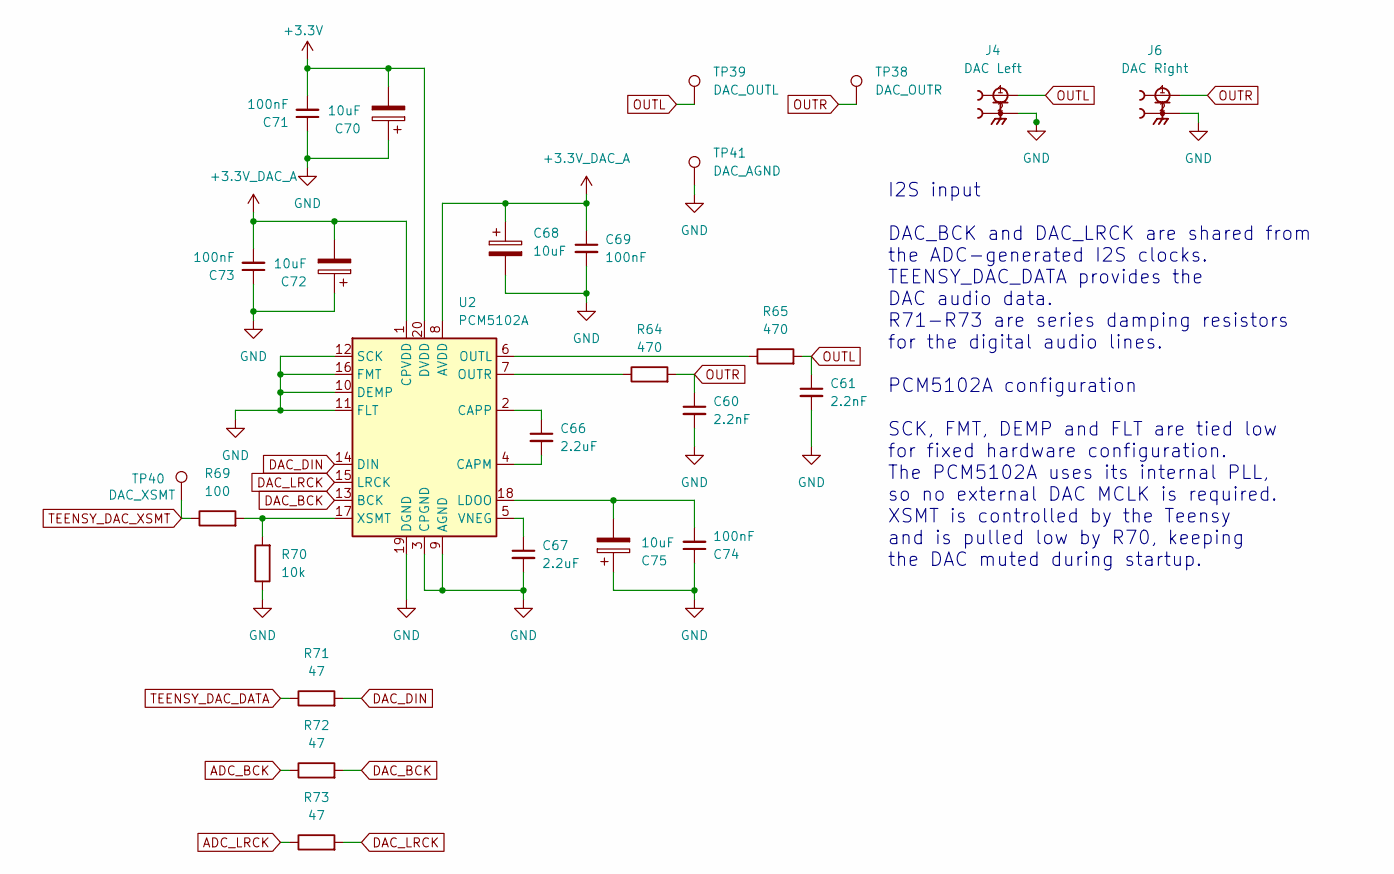
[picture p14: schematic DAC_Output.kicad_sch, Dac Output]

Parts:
C60, C61: 2.2nF; C_0603_1608Metric_Pad1.08x0.95mm_HandSolder
C66, C67: 2.2uF; C_1206_3216Metric
C68, C70, C72, C75: 10uF; C_0805_2012Metric
C69, C71, C73, C74: 100nF; C_0603_1608Metric_Pad1.08x0.95mm_HandSolder
J4: DAC Left; LINX_CONBNC002
J6: DAC Right; LINX_CONBNC002
R64, R65: 470; R_0603_1608Metric_Pad0.98x0.95mm_HandSolder
R69: 100; R_0603_1608Metric_Pad0.98x0.95mm_HandSolder
R70: 10k; R_0603_1608Metric_Pad0.98x0.95mm_HandSolder
R71, R72, R73: 47; R_0603_1608Metric_Pad0.98x0.95mm_HandSolder
TP38: DAC_OUTR; TestPoint_Pad_D1.5mm
TP39: DAC_OUTL; TestPoint_Pad_D1.5mm
TP40: DAC_XSMT; TestPoint_Pad_D1.5mm
TP41: DAC_AGND; TestPoint_Pad_D1.5mm
U2: PCM5102A; TSSOP-20_4.4x6.5mm_P0.65mm

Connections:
+3.3V: C70.2, C71.2, U2.20 (DVDD); also elsewhere on the board
+3.3V_DAC_A: C68.1, C69.1, C72.2, C73.2, U2.1 (CPVDD), U2.8 (AVDD); also elsewhere on the board
ADC_BCK: R72.1; also elsewhere on the board
ADC_LRCK: R73.1; also elsewhere on the board
DAC_BCK: R72.2, U2.13 (BCK)
DAC_DIN: R71.2, U2.14 (DIN)
DAC_LRCK: R73.2, U2.15 (LRCK)
GND: C60.2, C61.2, C67.2, C68.2, C69.2, C70.1, C71.1, C72.1, C73.1, C74.1, C75.1, J4.2, J4.S1, J4.S2, J6.2, J6.S1, J6.S2, R70.1, TP41.1 (1_1), U2.3 (CPGND), U2.9 (AGND), U2.10 (DEMP), U2.11 (FLT), U2.12 (SCK), U2.16 (FMT), U2.19 (DGND); also elsewhere on the board
unnamed: C66.2, U2.4 (CAPM)
unnamed: C66.1, U2.2 (CAPP)
unnamed: C74.2, C75.2, U2.18 (LDOO)
unnamed: R65.1, U2.6 (OUTL)
unnamed: R64.1, U2.7 (OUTR)
unnamed: C67.1, U2.5 (VNEG)
unnamed: R69.2, R70.2, U2.17 (XSMT)
OUTL: C61.1, J4.1, R65.2, TP39.1 (1_1); also elsewhere on the board
OUTR: C60.1, J6.1, R64.2, TP38.1 (1_1); also elsewhere on the board
TEENSY_DAC_DATA: R71.1; also elsewhere on the board
TEENSY_DAC_XSMT: R69.1, TP40.1 (1_1); also elsewhere on the board

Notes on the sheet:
I2S input DAC_BCK and DAC_LRCK are shared from the ADC-generated I2S clocks. TEENSY_DAC_DATA provides the DAC audio data. R71-R73 are series damping resistors for the digital audio lines. PCM5102A configuration SCK, FMT, DEMP and FLT are tied low for fixed hardware configuration. The PCM5102A uses 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

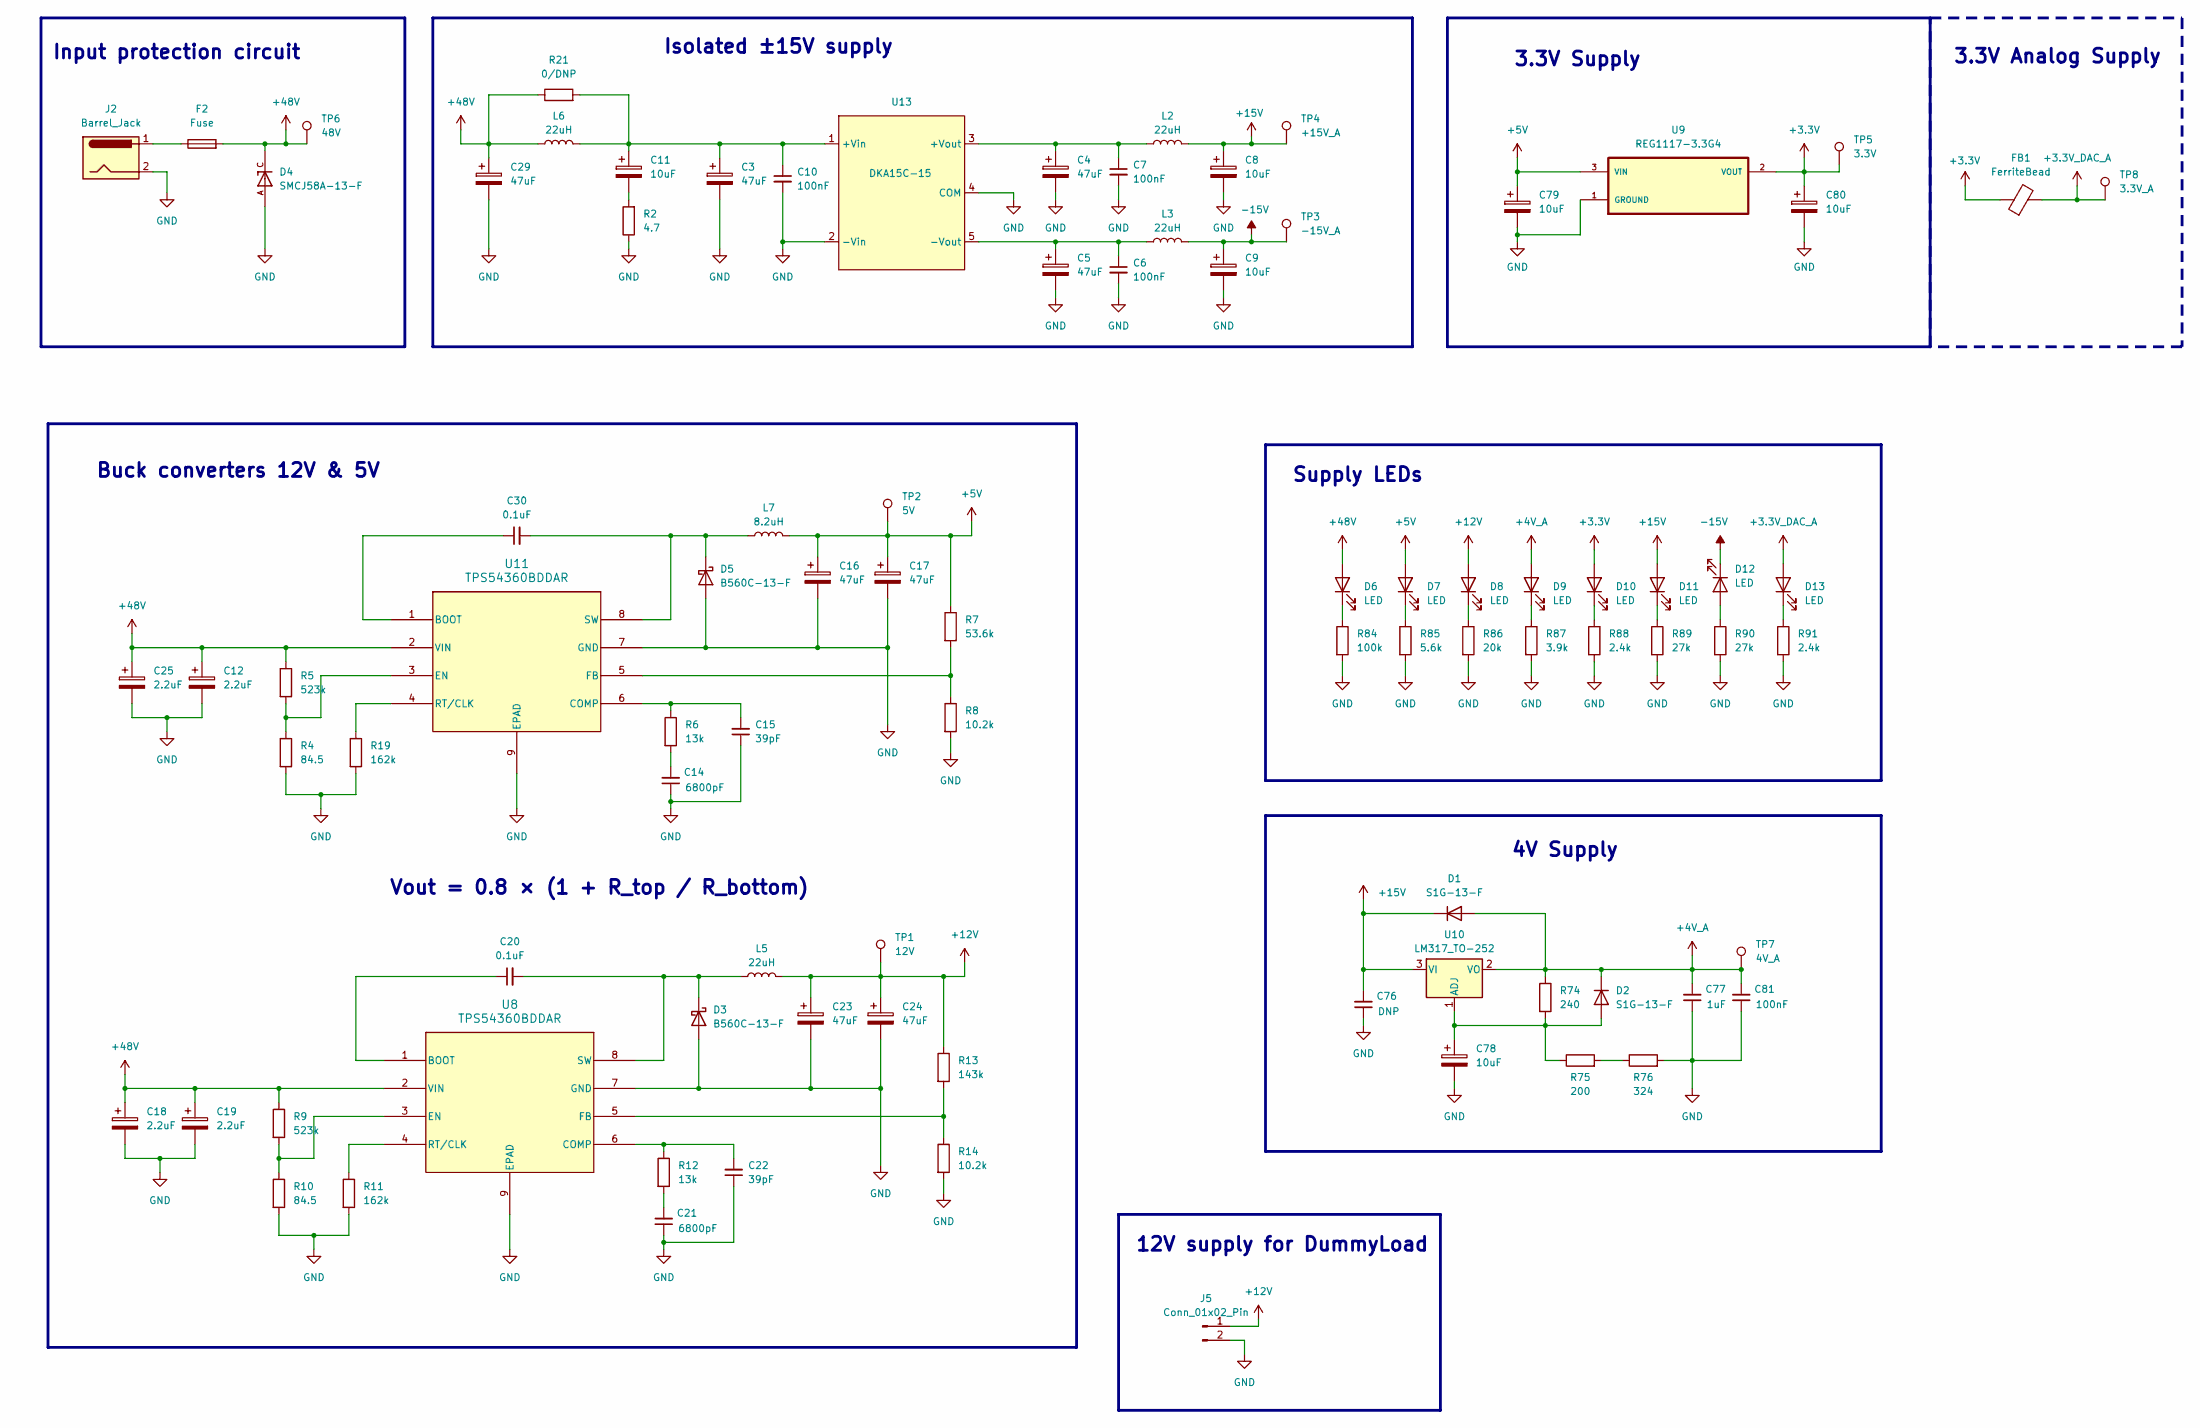
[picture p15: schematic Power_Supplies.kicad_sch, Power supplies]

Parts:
C3, C29: 47uF; CP_Elec_10x10.5
C4, C5, C23, C24: 47uF; CP_Elec_6.3x7.7
C6, C7, C81: 100nF; C_0603_1608Metric_Pad1.08x0.95mm_HandSolder
C8, C9: 10uF; C_1206_3216Metric
C10: 100nF; C_0805_2012Metric
C11: 10uF; CP_Elec_8x10.5
C12, C18, C19: 2.2uF; C_1210_3225Metric
C14, C21: 6800pF; C_0603_1608Metric_Pad1.08x0.95mm_HandSolder
C15, C22: 39pF; C_0603_1608Metric_Pad1.08x0.95mm_HandSolder
C16, C17: 47uF; C_1210_3225Metric
C20, C30: 0.1uF; C_0603_1608Metric_Pad1.08x0.95mm_HandSolder
C25: 2.2uF; C_1210_3225Metric_Pad1.33x2.70mm_HandSolder
C76: DNP; C_0603_1608Metric_Pad1.08x0.95mm_HandSolder
C77: 1uF; C_0603_1608Metric_Pad1.08x0.95mm_HandSolder
C78: 10uF; C_0805_2012Metric
C79, C80: 10uF; CP_EIA-3216-18_Kemet-A
D1, D2: S1G-13-F; D_SMA
D3, D5: B560C-13-F; D_SMC_Handsoldering
D4: SMCJ58A-13-F; DIOM7959X250N; PARTREV 5-2
D6, D7, D8, D9, D10, D11, D12, D13: LED; LED_0603_1608Metric_Pad1.05x0.95mm_HandSolder
F2: Fuse; 0451Series_LTF-M
FB1: FerriteBead; BEADC2012X105N
J2: Barrel_Jack; BarrelJack_CUI_PJ-063AH_Horizontal
J5: Conn_01x02_Pin; PhoenixContact_MSTBA_2,5_2-G-5,08_1x02_P5.08mm_Horizontal
L2, L3, L5, L6: 22uH; IND_HCM1A0805V2_EAT-L
L7: 8.2uH; WE-PD_1030P
R2: 4.7; R_1206_3216Metric_Pad1.30x1.75mm_HandSolder
R4, R10: 84.5; R_0603_1608Metric_Pad0.98x0.95mm_HandSolder
R5, R9: 523k; R_0805_2012Metric_Pad1.20x1.40mm_HandSolder
R6, R12: 13k; R_0603_1608Metric_Pad0.98x0.95mm_HandSolder
R7: 53.6k; R_0603_1608Metric_Pad0.98x0.95mm_HandSolder
R8, R14: 10.2k; R_0603_1608Metric_Pad0.98x0.95mm_HandSolder
R11, R19: 162k; R_0603_1608Metric_Pad0.98x0.95mm_HandSolder
R13: 143k; R_0603_1608Metric_Pad0.98x0.95mm_HandSolder
R21: 0/DNP; R_0603_1608Metric_Pad0.98x0.95mm_HandSolder
R74: 240; R_0603_1608Metric_Pad0.98x0.95mm_HandSolder
R75: 200; R_0603_1608Metric_Pad0.98x0.95mm_HandSolder
R76: 324; R_0603_1608Metric_Pad0.98x0.95mm_HandSolder
R84: 100k; R_1206_3216Metric_Pad1.30x1.75mm_HandSolder
R85: 5.6k; R_0603_1608Metric_Pad0.98x0.95mm_HandSolder
R86: 20k; R_0603_1608Metric_Pad0.98x0.95mm_HandSolder
R87: 3.9k; R_0603_1608Metric_Pad0.98x0.95mm_HandSolder
R88, R91: 2.4k; R_0603_1608Metric_Pad0.98x0.95mm_HandSolder
R89, R90: 27k; R_0603_1608Metric_Pad0.98x0.95mm_HandSolder
TP1: 12V; TestPoint_Pad_D1.5mm
TP2: 5V; TestPoint_Pad_D1.5mm
TP3: -15V_A; TestPoint_Pad_D1.5mm
TP4: +15V_A; TestPoint_Pad_D1.5mm
TP5: 3.3V; TestPoint_Pad_D1.5mm
TP6: 48V; TestPoint_Pad_D1.5mm
TP7: 4V_A; TestPoint_Pad_D1.5mm
TP8: 3.3V_A; TestPoint_Pad_D1.5mm
U8, U11: TPS54360BDDAR; U_DDA_TEX-M
U9: REG1117-3.3G4; SOT230P700X180-4N
U10: LM317_TO-252; TO-252-2
U13: DKA15C-15; DKA15C

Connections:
+3.3V: C80.1, D10.2 (A), FB1.1, TP5.1 (1_1), U9.2 (VOUT), U9.4 (VOUT); also elsewhere on the board
+3.3V_DAC_A: D13.2 (A), FB1.2, TP8.1 (1_1); also elsewhere on the board
+4V_A: C77.2, C81.2, D1.2 (A), D2.1 (K), D9.2 (A), R74.1, TP7.1 (1_1), U10.2 (VO); also elsewhere on the board
+5V: C16.1, C17.1, C79.1, D7.2 (A), L7.2, R7.1, TP2.1 (1_1), U9.3 (VIN); also elsewhere on the board
+12V: C23.1, C24.1, D8.2 (A), J5.1, L5.2, R13.1, TP1.1 (1_1); also elsewhere on the board
+15V: C8.1, C76.2, D1.1 (K), D11.2 (A), L2.2, TP4.1 (1_1), U10.3 (VI); also elsewhere on the board
+48V: C12.1, C18.1, C19.1, C25.1, C29.1, D4.C, D6.2 (A), F2.2, L6.1, R5.1, R9.1, R21.1, TP6.1 (1_1), U8.2 (VIN), U11.2 (VIN)
-15V: C9.1, D12.1 (K), L3.2, TP3.1 (1_1); also elsewhere on the board
GND: C3.2, C4.2, C5.2, C6.2, C7.2, C8.2, C9.2, C10.2, C12.2, C14.1, C15.1, C16.2, C17.2, C18.2, C19.2, C21.1, C22.1, C23.2, C24.2, C25.2, C29.2, C76.1, C77.1, C78.2, C79.2, C80.2, C81.1, D3.2 (A), D4.A, D5.2 (A), J2.2, J2.MP, J5.2, R2.1, R4.2, R8.2, R10.2, R11.2, R14.2, R19.2, R76.2, R84.2, R85.2, R86.2, R87.2, R88.2, R89.2, R90.2, R91.2, U8.7 (GND), U8.9 (EPAD), U8.EPAD, U9.1 (GROUND), U11.7 (GND), U11.9 (EPAD), U11.EPAD, U13.2 (-Vin), U13.4 (COM); also elsewhere on the board
unnamed: C11.2, R2.2
unnamed: C14.2, R6.2
unnamed: C21.2, R12.2
unnamed: C78.1, D2.2 (A), R74.2, R75.1, U10.1 (ADJ)
unnamed: C20.2, D3.1 (K), L5.1, U8.8 (SW)
unnamed: C30.2, D5.1 (K), L7.1, U11.8 (SW)
unnamed: D6.1 (K), R84.1
unnamed: D7.1 (K), R85.1
unnamed: D8.1 (K), R86.1
unnamed: D9.1 (K), R87.1
unnamed: D10.1 (K), R88.1
unnamed: D11.1 (K), R89.1
unnamed: D12.2 (A), R90.1
unnamed: D13.1 (K), R91.1
unnamed: F2.1, J2.1
unnamed: R75.2, R76.1
unnamed: C20.1, U8.1 (BOOT)
unnamed: C22.2, R12.1, U8.6 (COMP)
unnamed: R9.2, R10.1, U8.3 (EN)
unnamed: R13.2, R14.1, U8.5 (FB)
unnamed: R11.1, U8.4 (RT/CLK)
unnamed: C30.1, U11.1 (BOOT)
unnamed: C15.2, R6.1, U11.6 (COMP)
unnamed: R4.1, R5.2, U11.3 (EN)
unnamed: R7.2, R8.1, U11.5 (FB)
unnamed: R19.1, U11.4 (RT/CLK)
unnamed: C3.1, C10.1, C11.1, L6.2, R21.2, U13.1 (+Vin)
unnamed: C4.1, C7.1, L2.1, U13.3 (+Vout)
unnamed: C5.1, C6.1, L3.1, U13.5 (-Vout)

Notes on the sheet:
3.3V Analog Supply
Input protection circuit
Vout = 0.8 × (1 + R_top / R_bottom)
Buck converters 12V & 5V
Supply LEDs
4V Supply
3.3V Supply
Isolated ±15V supply
12V supply for DummyLoad

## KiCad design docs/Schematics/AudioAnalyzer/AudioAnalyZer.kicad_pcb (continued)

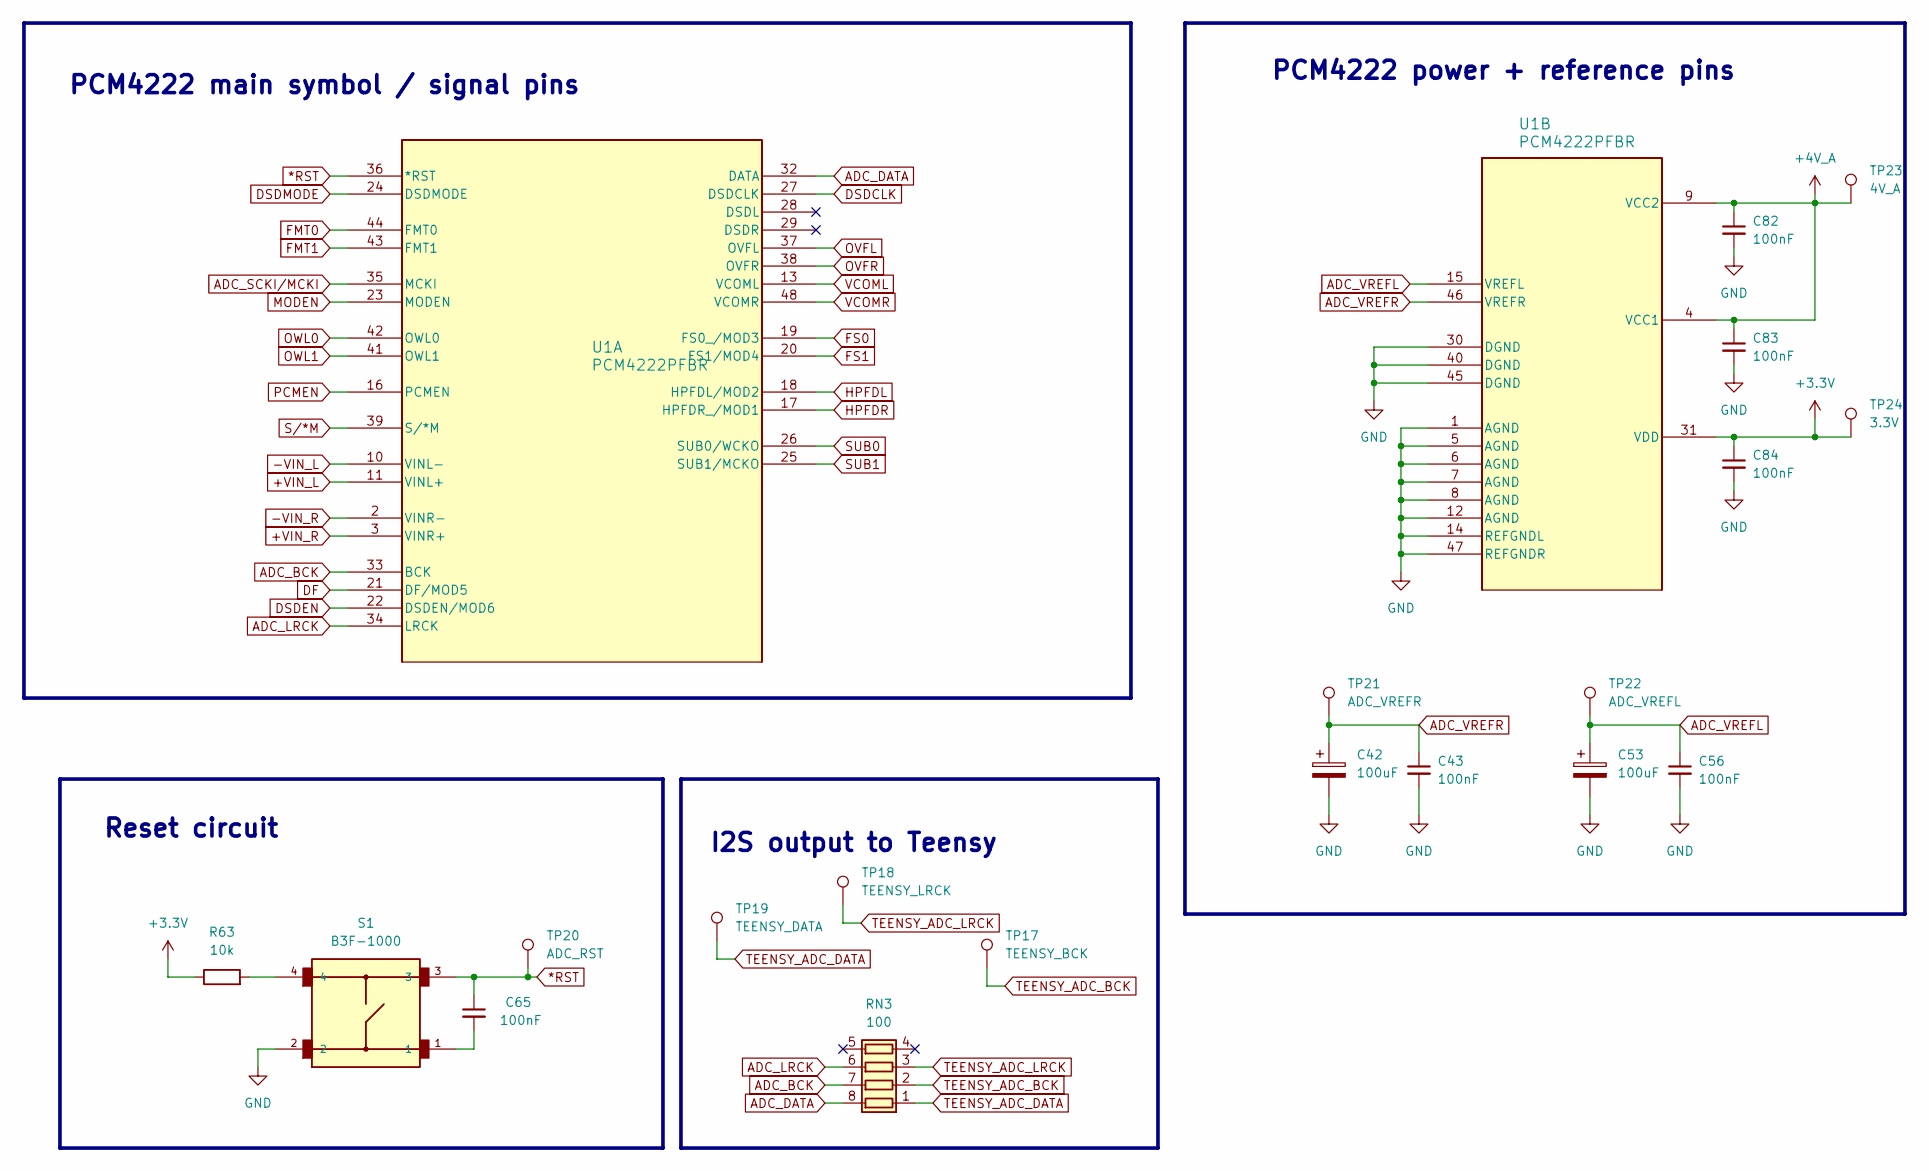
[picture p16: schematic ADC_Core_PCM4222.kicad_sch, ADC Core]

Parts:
C42, C53: 100uF; C_1210_3225Metric
C43, C56, C65, C82, C83, C84: 100nF; C_0603_1608Metric_Pad1.08x0.95mm_HandSolder
R63: 10k; R_0603_1608Metric_Pad0.98x0.95mm_HandSolder
RN3: 100; RESCAXS80P320X160X60-8N
S1: B3F-1000; SW_B3F-1000
TP17: TEENSY_BCK; TestPoint_Pad_D1.5mm
TP18: TEENSY_LRCK; TestPoint_Pad_D1.5mm
TP19: TEENSY_DATA; TestPoint_Pad_D1.5mm
TP20: ADC_RST; TestPoint_Pad_D1.5mm
TP21: ADC_VREFR; TestPoint_Pad_D1.5mm
TP22: ADC_VREFL; TestPoint_Pad_D1.5mm
TP23: 4V_A; TestPoint_Pad_D1.5mm
TP24: 3.3V; TestPoint_Pad_D1.5mm
U1: PCM4222PFBR; PFB48-M

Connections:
*RST: C65.1, S1.3, TP20.1 (1_1), U1.36 (*RST)
+3.3V: C84.1, R63.1, TP24.1 (1_1), U1.31 (VDD); also elsewhere on the board
+4V_A: C82.1, C83.1, TP23.1, U1.4 (VCC1), U1.9 (VCC2); also elsewhere on the board
+VIN_L: U1.11 (VINL+); also elsewhere on the board
+VIN_R: U1.3 (VINR+); also elsewhere on the board
-VIN_L: U1.10 (VINL-); also elsewhere on the board
-VIN_R: U1.2 (VINR-); also elsewhere on the board
ADC_BCK: RN3.7 (R2.2), U1.33 (BCK); also elsewhere on the board
ADC_DATA: RN3.8 (R1.2), U1.32 (DATA)
ADC_LRCK: RN3.6 (R3.2), U1.34 (LRCK); also elsewhere on the board
ADC_SCKI/MCKI: U1.35 (MCKI); also elsewhere on the board
ADC_VREFL: C53.1, C56.1, TP22.1 (1_1), U1.15 (VREFL)
ADC_VREFR: C42.1, C43.1, TP21.1 (1_1), U1.46 (VREFR)
DF: U1.21 (DF/MOD5); also elsewhere on the board
DSDCLK: U1.27 (DSDCLK)
DSDEN: U1.22 (DSDEN/MOD6); also elsewhere on the board
DSDMODE: U1.24 (DSDMODE); also elsewhere on the board
FMT0: U1.44 (FMT0); also elsewhere on the board
FMT1: U1.43 (FMT1); also elsewhere on the board
FS0: U1.19 (FS0_/MOD3); also elsewhere on the board
FS1: U1.20 (FS1/MOD4); also elsewhere on the board
GND: C42.2, C43.2, C53.2, C56.2, C82.2, C83.2, C84.2, S1.2, U1.1 (AGND), U1.5 (AGND), U1.6 (AGND), U1.7 (AGND), U1.8 (AGND), U1.12 (AGND), U1.14 (REFGNDL), U1.30 (DGND), U1.40 (DGND), U1.45 (DGND), U1.47 (REFGNDR); also elsewhere on the board
HPFDL: U1.17 (HPFDR_/MOD1), U1.18 (HPFDL/MOD2); also elsewhere on the board
MODEN: U1.23 (MODEN); also elsewhere on the board
unnamed: C65.2, S1.1
unnamed: R63.2, S1.4
OVFL: U1.37 (OVFL); also elsewhere on the board
OVFR: U1.38 (OVFR); also elsewhere on the board
OWL0: U1.42 (OWL0); also elsewhere on the board
OWL1: U1.41 (OWL1); also elsewhere on the board
PCMEN: U1.16 (PCMEN); also elsewhere on the board
SUB0: U1.26 (SUB0/WCKO); also elsewhere on the board
SUB1: U1.25 (SUB1/MCKO); also elsewhere on the board
S/*M: U1.39 (S/*M); also elsewhere on the board
TEENSY_ADC_BCK: RN3.2 (R2.1), TP17.1 (1_1); also elsewhere on the board
TEENSY_ADC_DATA: RN3.1 (R1.1), TP19.1 (1_1); also elsewhere on the board
TEENSY_ADC_LRCK: RN3.3 (R3.1), TP18.1 (1_1); also elsewhere on the board
VCOML: U1.13 (VCOML); also elsewhere on the board
VCOMR: U1.48 (VCOMR); also elsewhere on the board

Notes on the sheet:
PCM4222 main symbol / signal pins
I2S output to Teensy
PCM4222 power + reference pins
Reset circuit

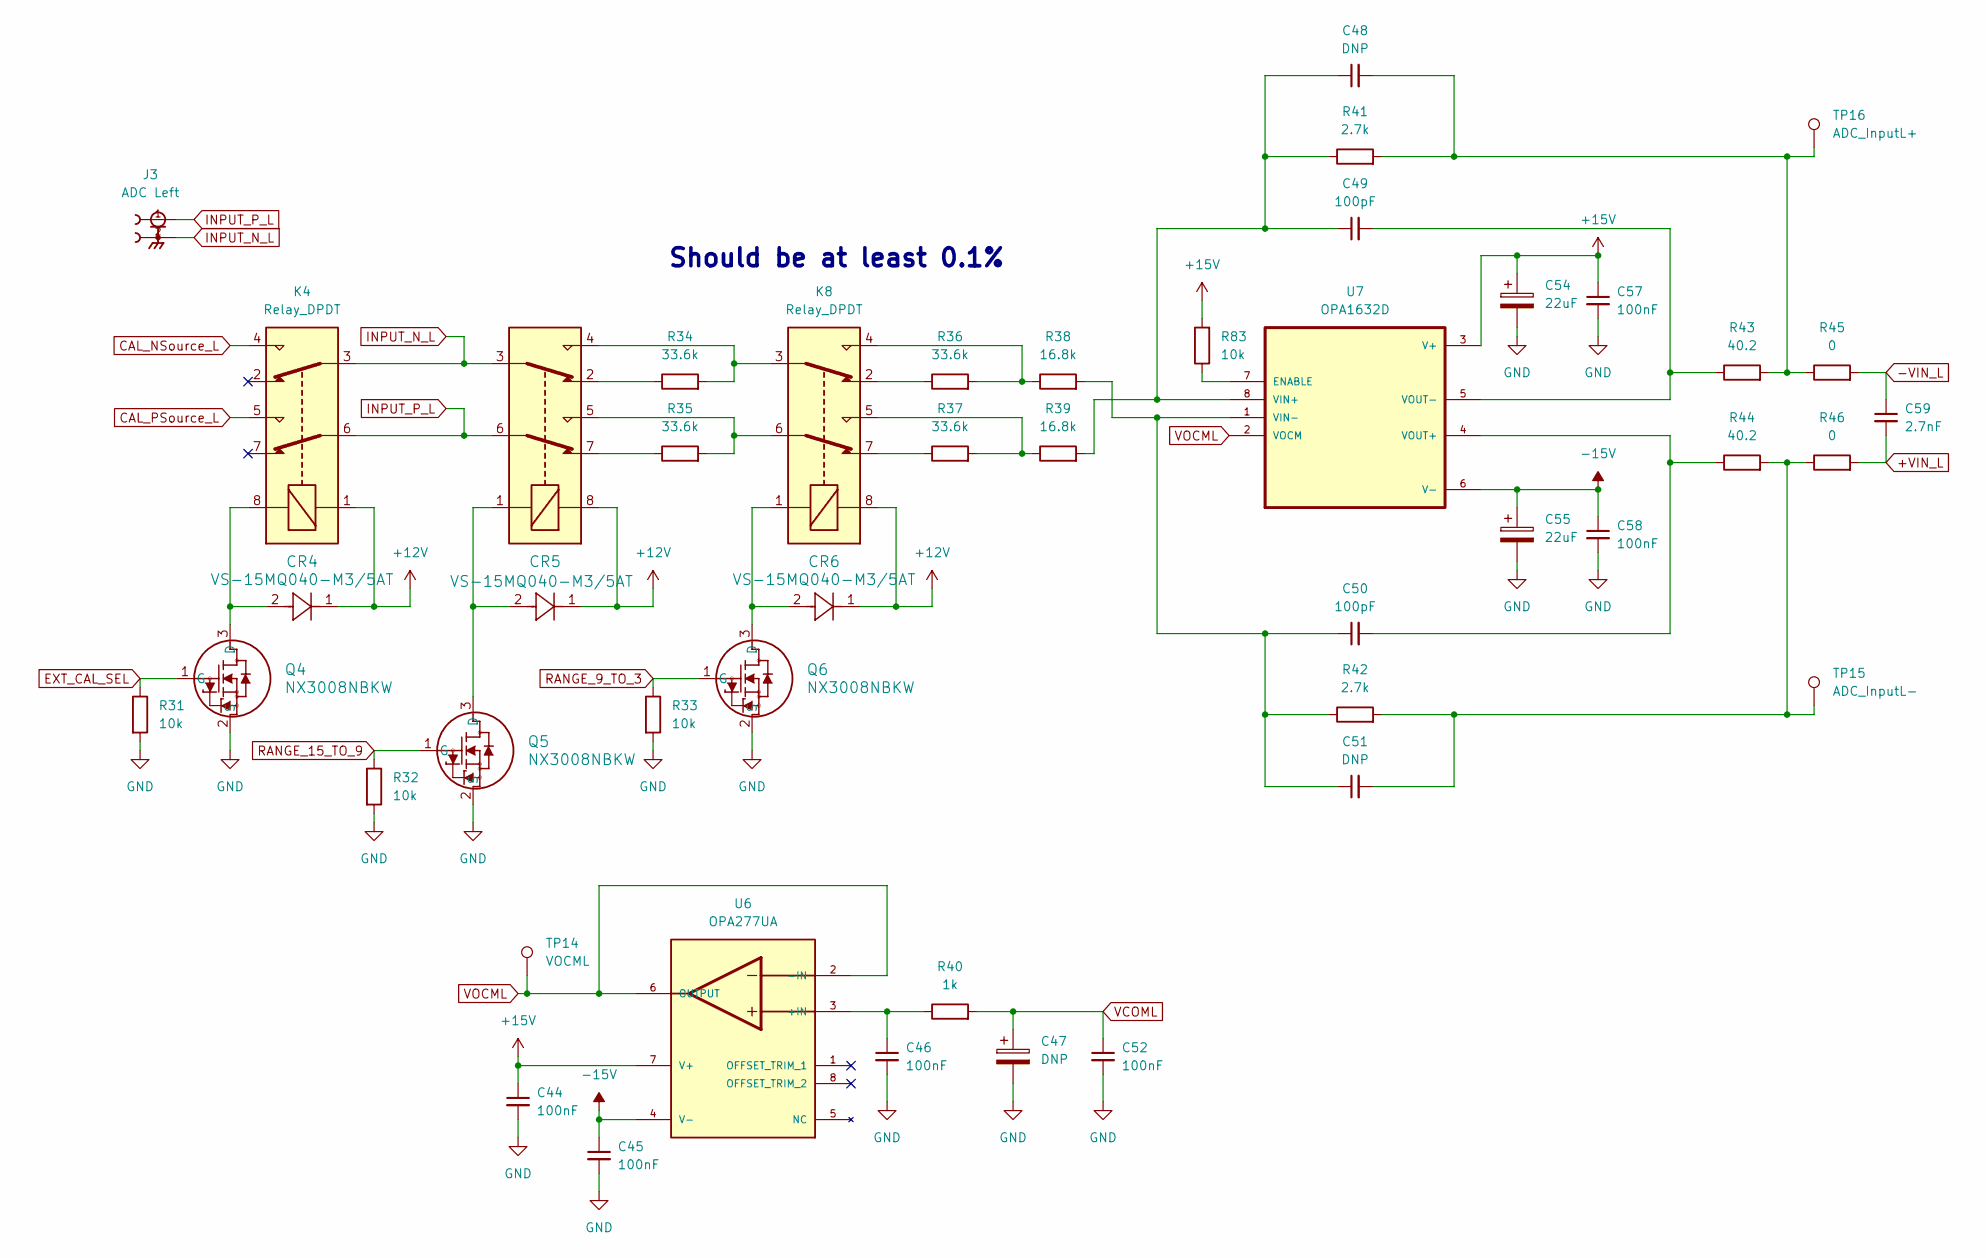
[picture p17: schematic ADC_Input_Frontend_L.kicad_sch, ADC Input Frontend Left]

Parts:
C44, C45, C46, C52, C57, C58: 100nF; C_0603_1608Metric_Pad1.08x0.95mm_HandSolder
C47, C48, C51: DNP; C_0603_1608Metric_Pad1.08x0.95mm_HandSolder
C49, C50: 100pF; C_0603_1608Metric_Pad1.08x0.95mm_HandSolder
C54, C55: 22uF; C_1206_3216Metric
C59: 2.7nF; C_0603_1608Metric_Pad1.08x0.95mm_HandSolder
CR4, CR5, CR6: VS-15MQ040-M3/5AT; CR_Q040-M3&slash_5AT_VIS
J3: ADC Left; LINX_CONBNC002
K4, K7, K8: Relay_DPDT; RELAY_IM06DGR
Q4, Q5, Q6: NX3008NBKW; SC-70_SOT323_NEX
R31, R32, R33, R83: 10k; R_0603_1608Metric_Pad0.98x0.95mm_HandSolder
R34, R35, R36, R37: 33.6k; R_0603_1608Metric_Pad0.98x0.95mm_HandSolder
R38, R39: 16.8k; R_0603_1608Metric_Pad0.98x0.95mm_HandSolder
R40: 1k; R_0603_1608Metric_Pad0.98x0.95mm_HandSolder
R41, R42: 2.7k; R_0603_1608Metric_Pad0.98x0.95mm_HandSolder
R43, R44: 40.2; R_0603_1608Metric_Pad0.98x0.95mm_HandSolder
R45, R46: 0; R_0603_1608Metric_Pad0.98x0.95mm_HandSolder
TP14: VOCML; TestPoint_Pad_D1.5mm
TP15: ADC_InputL-; TestPoint_Pad_D1.5mm
TP16: ADC_InputL+; TestPoint_Pad_D1.5mm
U6: OPA277UA; SOIC127P599X175-8N; PARTREV 02/2019
U7: OPA1632D; SOIC127P599X175-8N

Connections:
+12V: CR4.1, CR5.1, CR6.1, K4.1, K7.8, K8.8; also elsewhere on the board
+15V: C44.1, C54.1, C57.1, R83.2, U6.7 (V+), U7.3 (V+); also elsewhere on the board
+VIN_L: C59.2, R46.2; also elsewhere on the board
-15V: C45.1, C55.1, C58.1, U6.4 (V-), U7.6 (V-); also elsewhere on the board
-VIN_L: C59.1, R45.2; also elsewhere on the board
CAL_NSource_L: K4.4; also elsewhere on the board
CAL_PSource_L: K4.5; also elsewhere on the board
EXT_CAL_SEL: Q4.1 (G), R31.1; also elsewhere on the board
GND: C44.2, C45.2, C46.2, C47.2, C52.2, C54.2, C55.2, C57.2, C58.2, Q4.2 (S), Q5.2 (S), Q6.2 (S), R31.2, R32.2, R33.2; also elsewhere on the board
INPUT_N_L: J3.2, J3.S1, J3.S2, K4.3, K7.3
INPUT_P_L: J3.1, K4.6, K7.6
unnamed: C48.2, R41.2, R43.2, R45.1, TP16.1 (1_1)
unnamed: C51.2, R42.2, R44.2, R46.1, TP15.1 (1_1)
unnamed: K7.2, R34.1
unnamed: K7.4, K8.3, R34.2
unnamed: K7.5, K8.6, R35.2
unnamed: K7.7, R35.1
unnamed: K8.2, R36.1
unnamed: K8.4, R36.2, R38.1
unnamed: K8.5, R37.2, R39.1
unnamed: K8.7, R37.1
unnamed: CR4.2, K4.8, Q4.3 (D)
unnamed: CR5.2, K7.1, Q5.3 (D)
unnamed: CR6.2, K8.1, Q6.3 (D)
unnamed: C46.1, R40.1, U6.3 (+IN)
unnamed: R83.1, U7.7 (ENABLE)
unnamed: C48.1, C49.1, R39.2, R41.1, U7.8 (VIN+)
unnamed: C50.1, C51.1, R38.2, R42.1, U7.1 (VIN-)
unnamed: C50.2, R44.1, U7.4 (VOUT+)
unnamed: C49.2, R43.1, U7.5 (VOUT-)
RANGE_9_TO_3: Q6.1 (G), R33.1; also elsewhere on the board
RANGE_15_TO_9: Q5.1 (G), R32.1; also elsewhere on the board
VCOML: C47.1, C52.1, R40.2; also elsewhere on the board
VOCML: TP14.1 (1_1), U6.2 (-IN), U6.6 (OUTPUT), U7.2 (VOCM)

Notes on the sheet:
Should be at least 0.1%

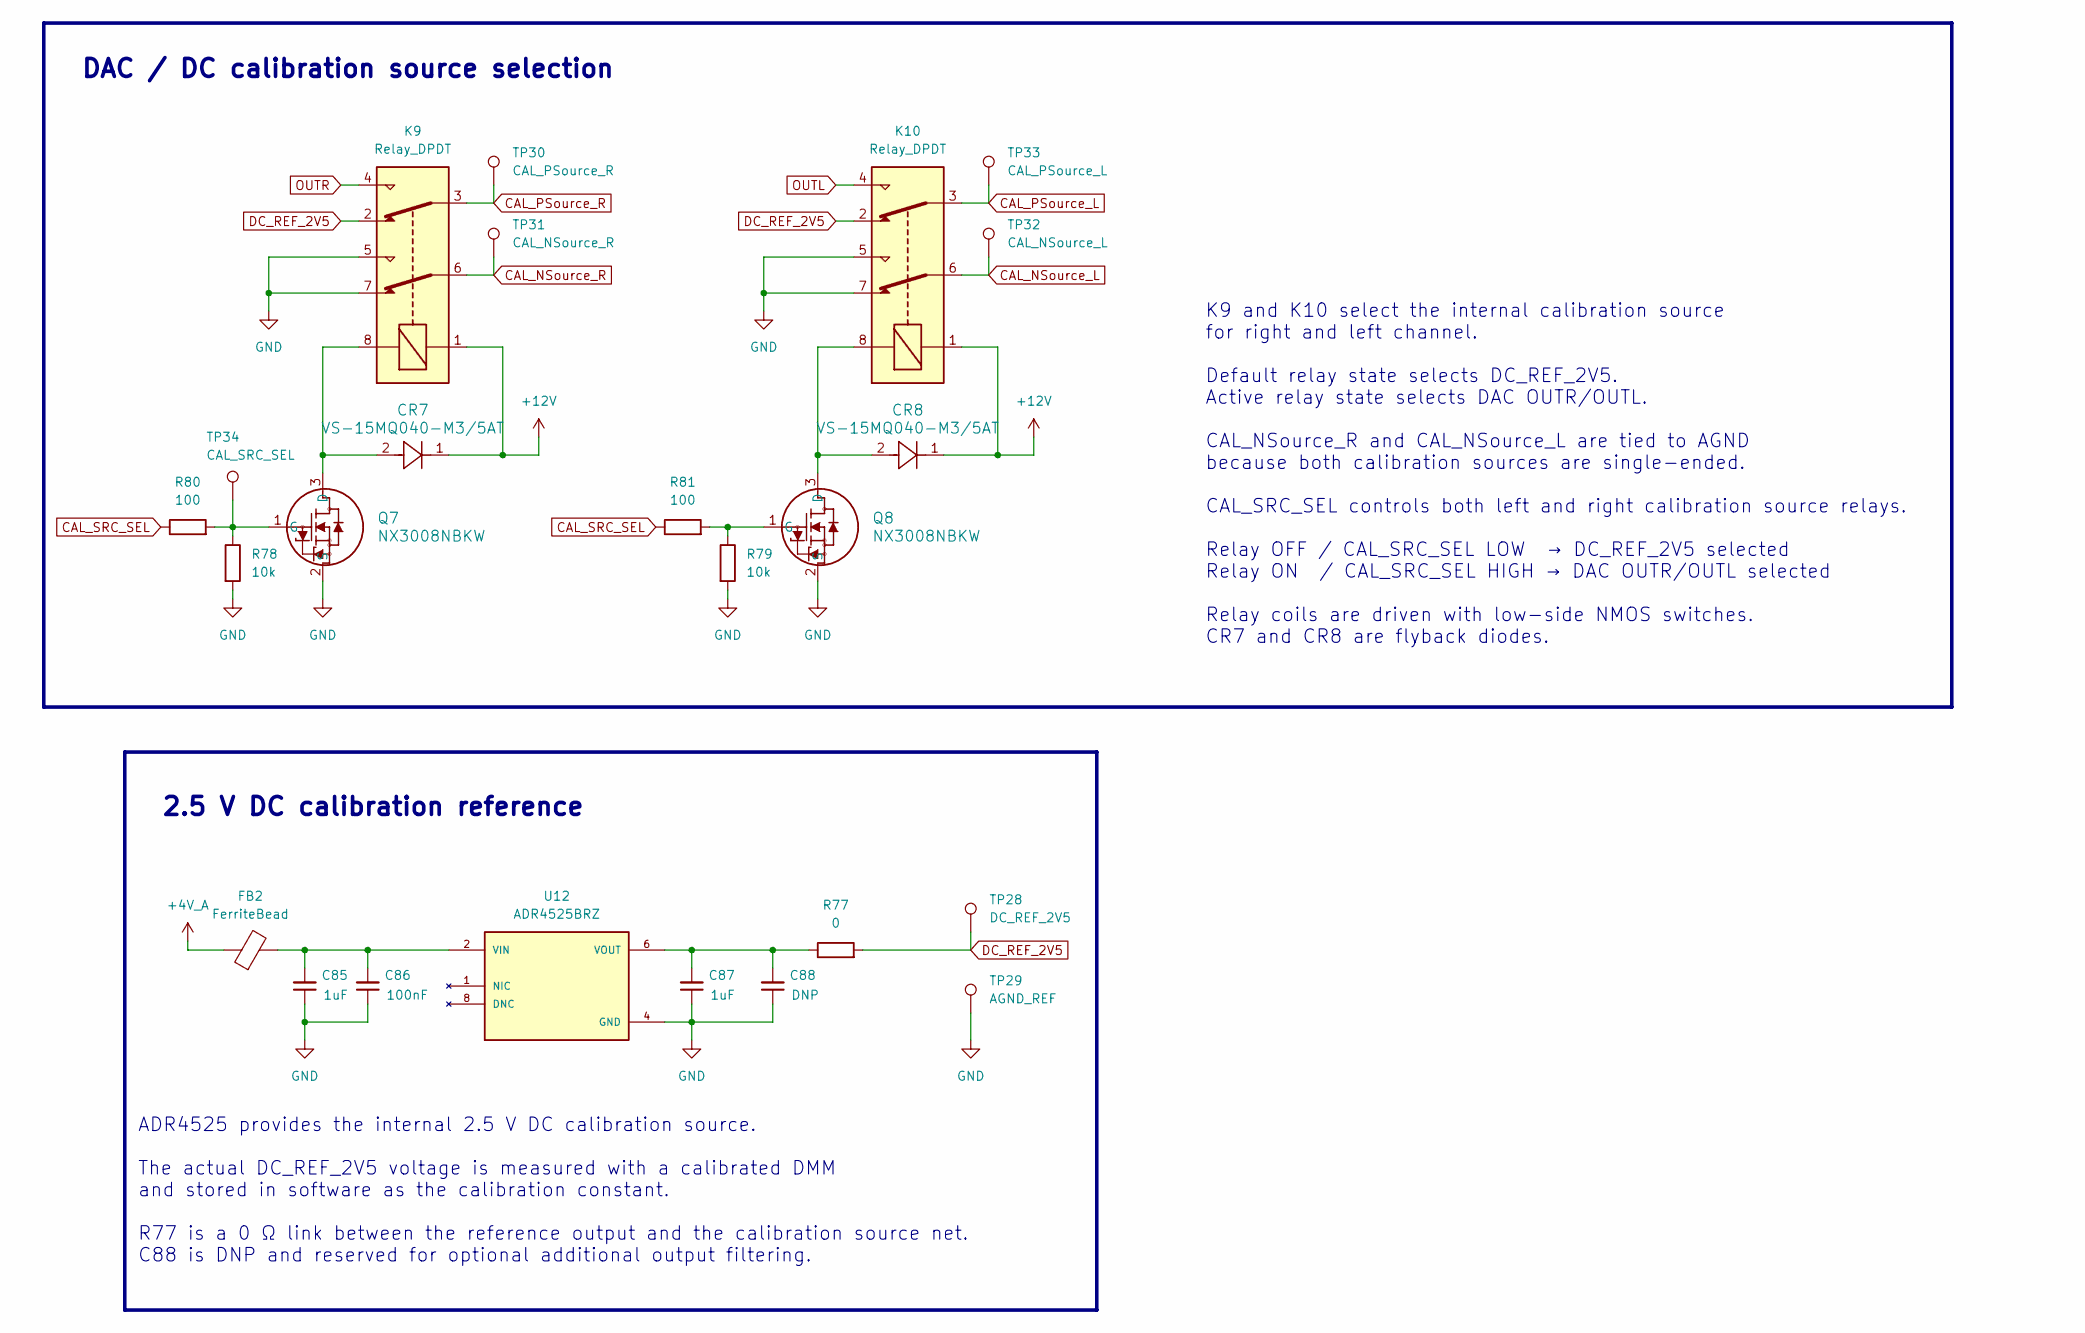
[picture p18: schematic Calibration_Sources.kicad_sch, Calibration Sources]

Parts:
C85, C87: 1uF; C_0603_1608Metric_Pad1.08x0.95mm_HandSolder
C86: 100nF; C_0603_1608Metric_Pad1.08x0.95mm_HandSolder
C88: DNP; C_0603_1608Metric_Pad1.08x0.95mm_HandSolder
CR7, CR8: VS-15MQ040-M3/5AT; CR_Q040-M3&slash_5AT_VIS
FB2: FerriteBead; BEADC2012X105N
K9, K10: Relay_DPDT; RELAY_IM06DGR
Q7, Q8: NX3008NBKW; SC-70_SOT323_NEX
R77: 0; R_0603_1608Metric_Pad0.98x0.95mm_HandSolder
R78, R79: 10k; R_0603_1608Metric_Pad0.98x0.95mm_HandSolder
R80, R81: 100; R_0603_1608Metric_Pad0.98x0.95mm_HandSolder
TP28: DC_REF_2V5; TestPoint_Pad_D1.5mm
TP29: AGND_REF; TestPoint_Pad_D1.5mm
TP30: CAL_PSource_R; TestPoint_Pad_D1.5mm
TP31: CAL_NSource_R; TestPoint_Pad_D1.5mm
TP32: CAL_NSource_L; TestPoint_Pad_D1.5mm
TP33: CAL_PSource_L; TestPoint_Pad_D1.5mm
TP34: CAL_SRC_SEL; TestPoint_Pad_D1.5mm
U12: ADR4525BRZ; SOIC127P600X175-8N; PARTREV G

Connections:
+4V_A: FB2.1; also elsewhere on the board
+12V: CR7.1, CR8.1, K9.1, K10.1; also elsewhere on the board
CAL_NSource_L: K10.6, TP32.1 (1_1); also elsewhere on the board
CAL_NSource_R: K9.6, TP31.1 (1_1); also elsewhere on the board
CAL_PSource_L: K10.3, TP33.1 (1_1); also elsewhere on the board
CAL_PSource_R: K9.3, TP30.1 (1_1); also elsewhere on the board
CAL_SRC_SEL: R80.1, R81.1; also elsewhere on the board
DC_REF_2V5: K9.2, K10.2, R77.2, TP28.1 (1_1)
GND: C85.1, C86.1, C87.1, C88.1, K9.5, K9.7, K10.5, K10.7, Q7.2 (S), Q8.2 (S), R78.2, R79.2, TP29.1 (1_1), U12.4 (GND); also elsewhere on the board
unnamed: CR7.2, K9.8, Q7.3 (D)
unnamed: Q7.1 (G), R78.1, R80.2, TP34.1 (1_1)
unnamed: CR8.2, K10.8, Q8.3 (D)
unnamed: Q8.1 (G), R79.1, R81.2
unnamed: C85.2, C86.2, FB2.2, U12.2 (VIN)
unnamed: C87.2, C88.2, R77.1, U12.6 (VOUT)
OUTL: K10.4; also elsewhere on the board
OUTR: K9.4; also elsewhere on the board

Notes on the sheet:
K9 and K10 select the internal calibration source for right and left channel. Default relay state selects DC_REF_2V5. Active relay state selects DAC OUTR/OUTL. CAL_NSource_R and CAL_NSource_L are tied to AGND because both calibration sources are single-ended. CAL_SRC_SEL controls both left and righ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
ADR4525 provides the internal 2.5 V DC calibration source. The actual DC_REF_2V5 voltage is measured with a calibrated DMM and stored in software as the calibration constant. R77 is a 0 Ω link between the reference output and the calibration source net. C88 is DNP and reserved for optional addition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
DAC / DC calibration source selection
2.5 V DC calibration reference

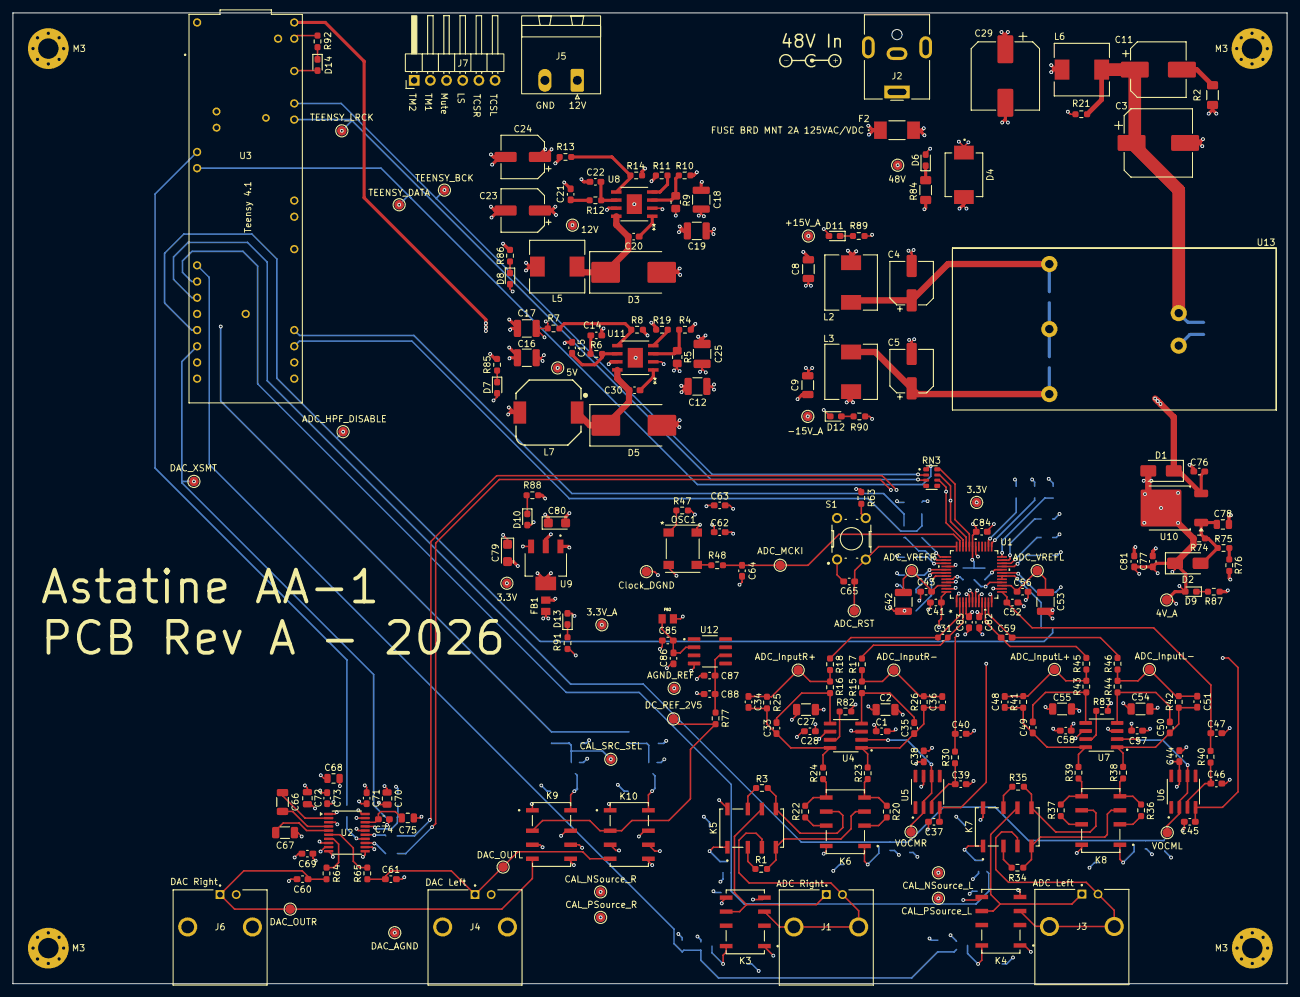
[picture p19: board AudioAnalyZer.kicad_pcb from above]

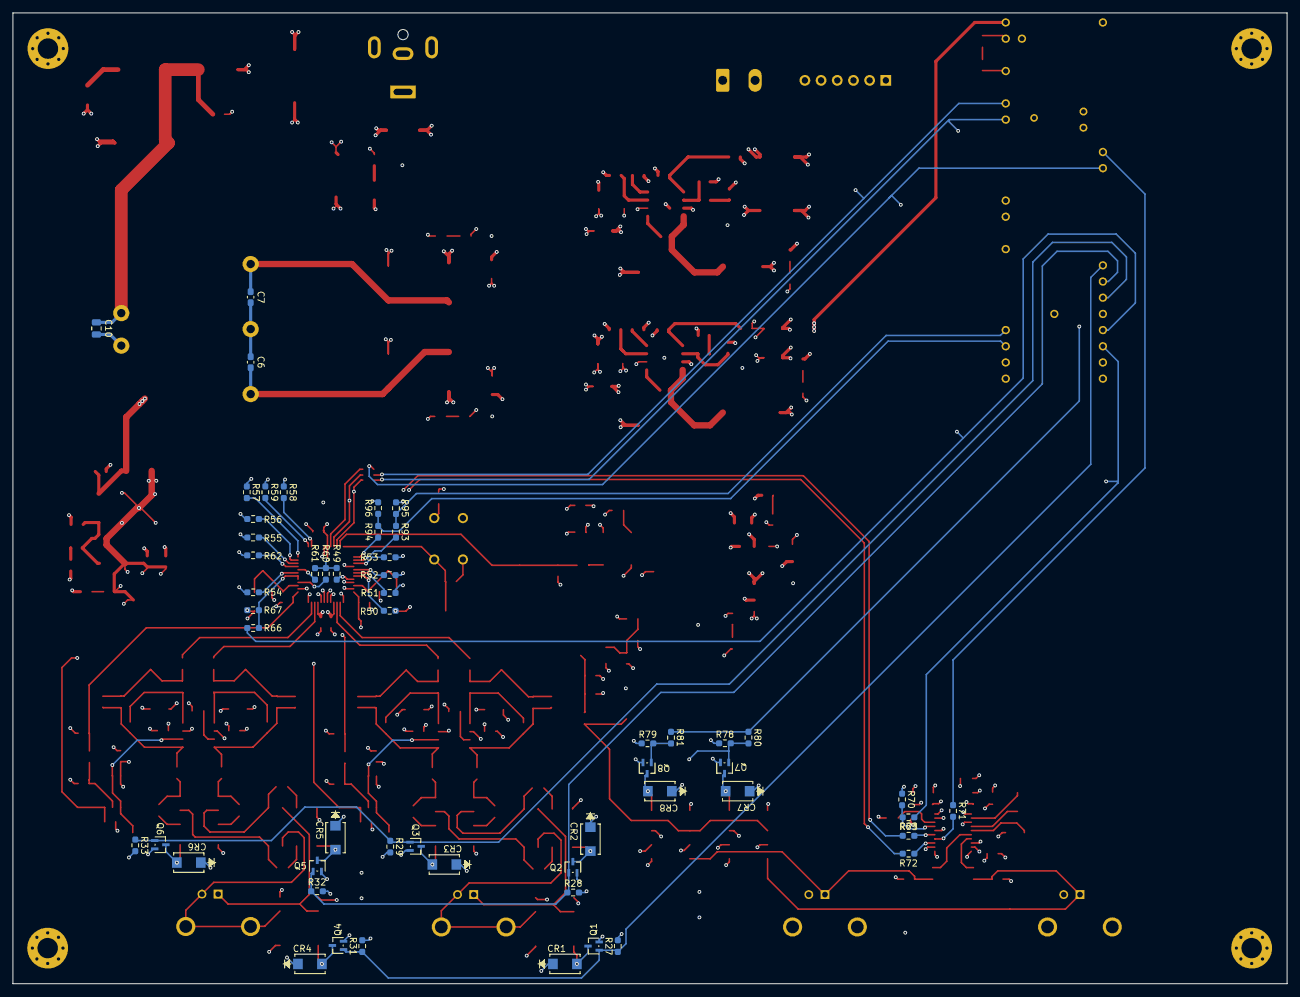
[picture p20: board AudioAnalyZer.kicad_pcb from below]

Board: 4 copper layers, 199.9 x 152.3 mm, 288 parts (54 on the bottom side), 159 nets.

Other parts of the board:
M3, M3#2, M3#3, M3#4: MountingHole_3.2mm_M3_Pad_Via

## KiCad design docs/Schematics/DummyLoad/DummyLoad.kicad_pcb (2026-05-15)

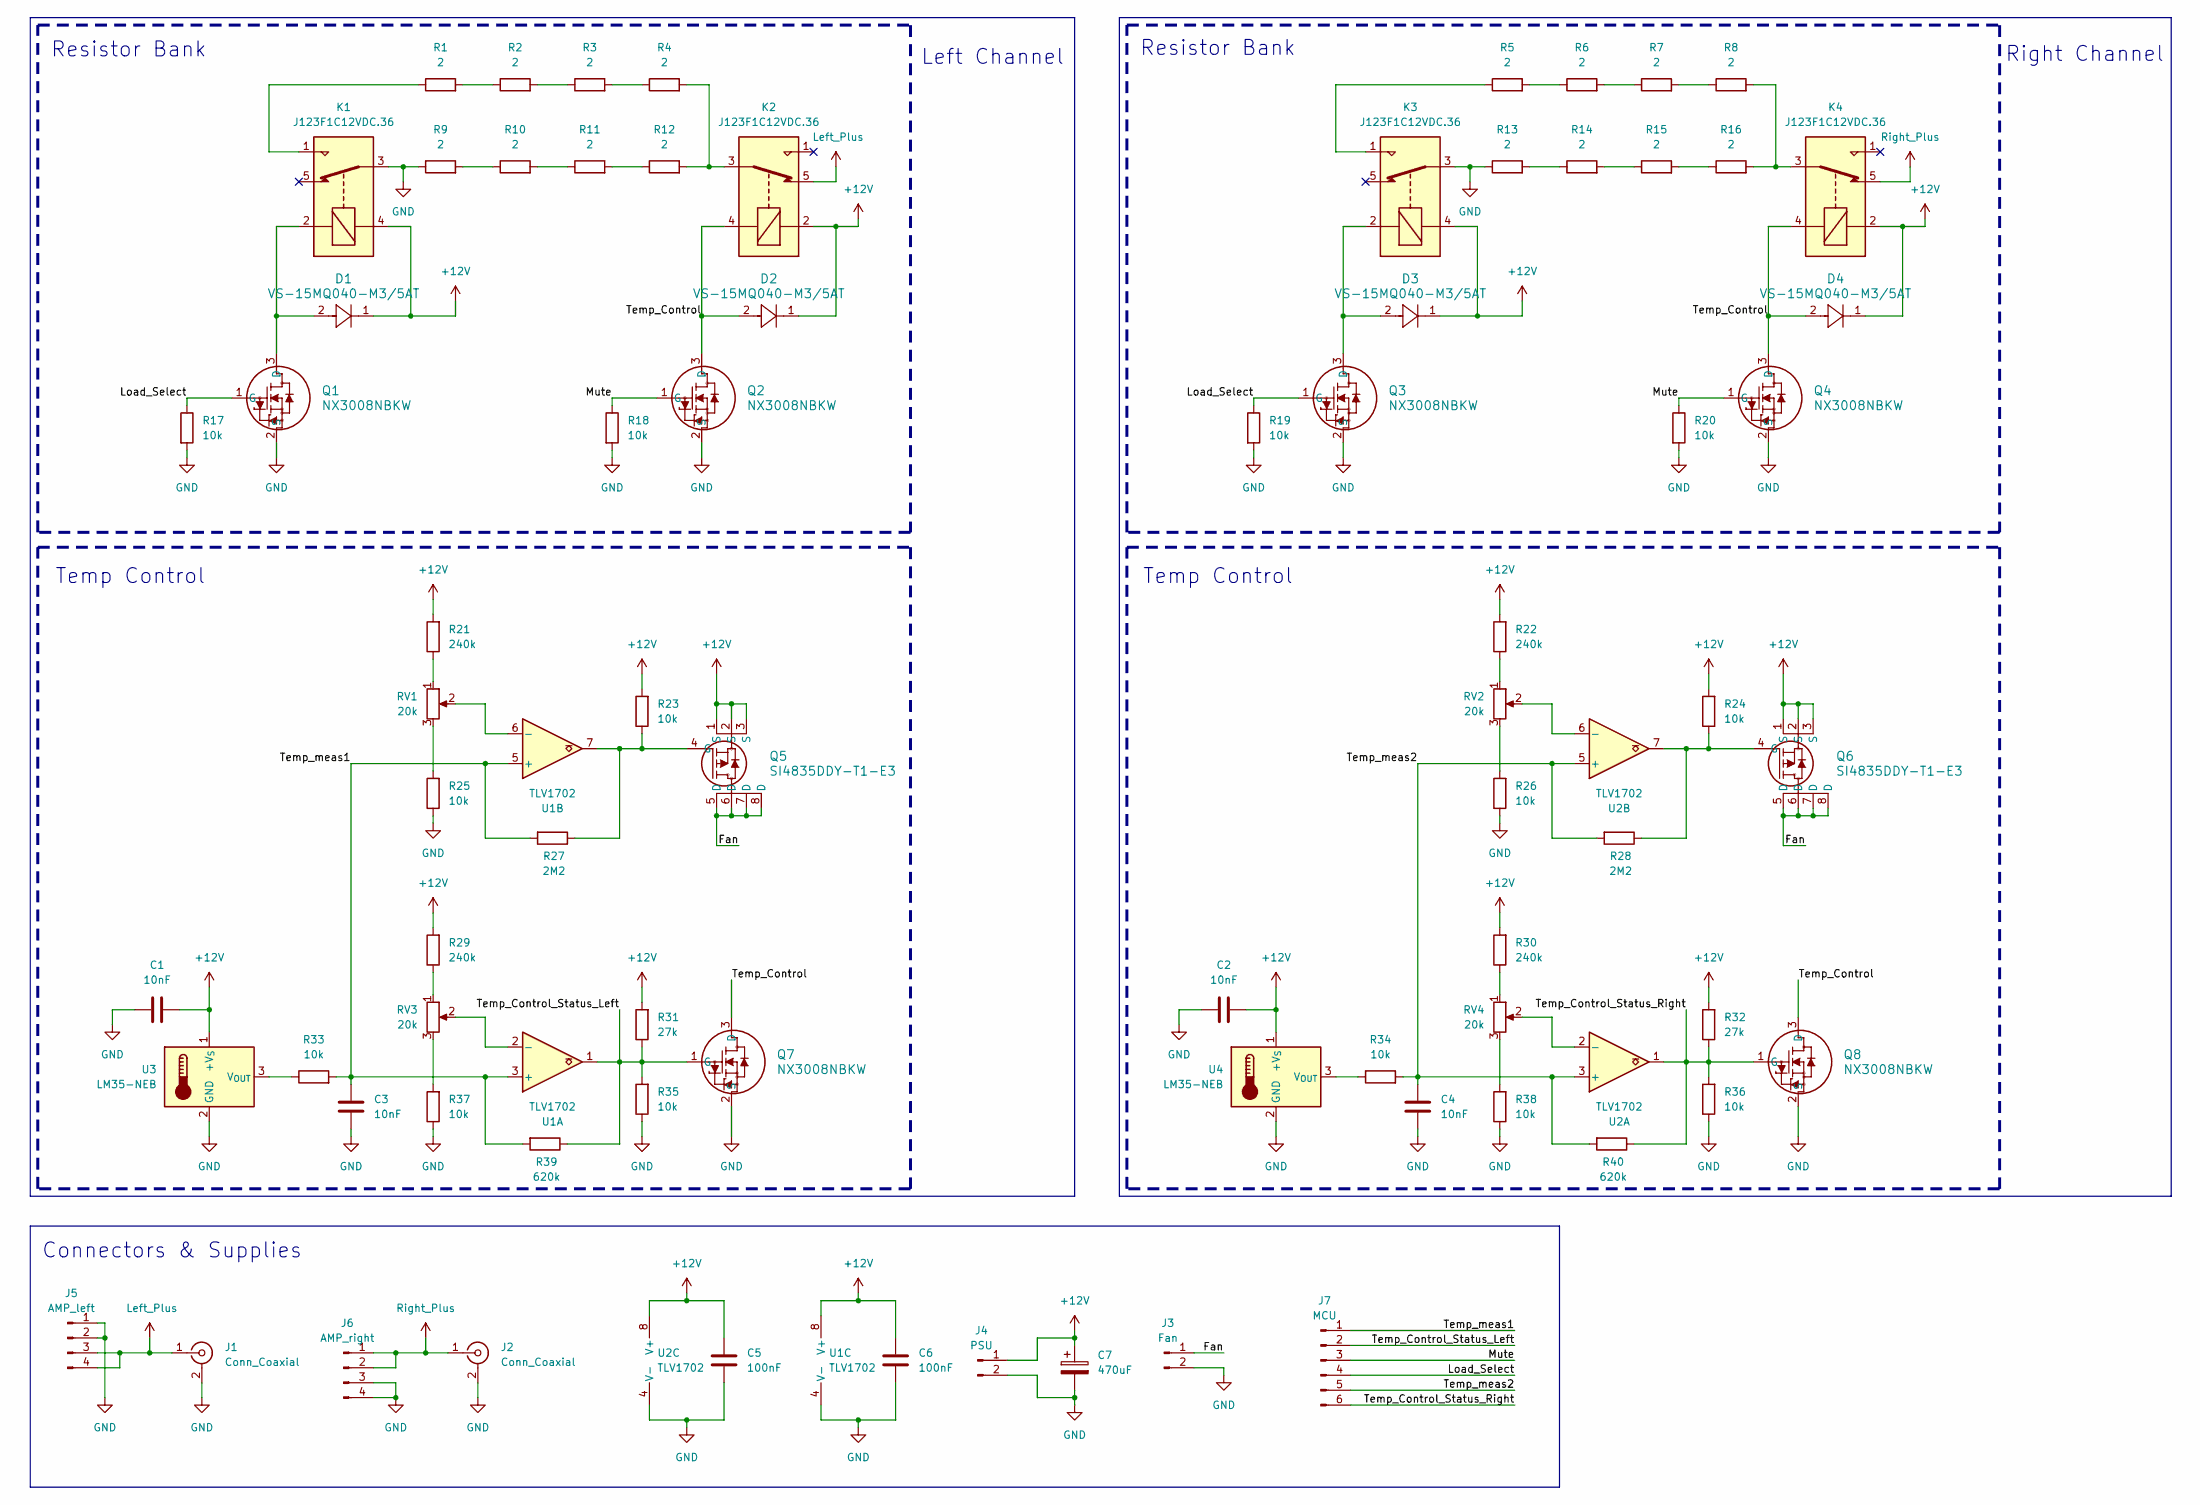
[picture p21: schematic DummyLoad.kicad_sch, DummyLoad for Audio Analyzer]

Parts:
C1, C2, C3, C4: 10nF; C_0603_1608Metric_Pad1.08x0.95mm_HandSolder
C5, C6: 100nF; C_0603_1608Metric_Pad1.08x0.95mm_HandSolder
C7: 470uF; CP_Radial_D10.0mm_P5.00mm
D1, D2, D3, D4: VS-15MQ040-M3/5AT; CR_Q040-M3&slash_5AT_VIS
J1, J2: Conn_Coaxial; LINX_CONBNC002
J3: Fan; PhoenixContact_MSTBA_2,5_2-G-5,08_1x02_P5.08mm_Horizontal
J4: PSU; PhoenixContact_MSTBA_2,5_2-G-5,08_1x02_P5.08mm_Horizontal
J5: AMP_left; PhoenixContact_MSTBA_2,5_4-G-5,08_1x04_P5.08mm_Horizontal
J6: AMP_right; PhoenixContact_MSTBA_2,5_4-G-5,08_1x04_P5.08mm_Horizontal
J7: MCU; PinHeader_1x06_P2.54mm_Vertical
K1, K2, K3, K4: J123F1C12VDC.36; RELAY5_J123F1C5VDC.36_CRS
Q1, Q2, Q3, Q4, Q7, Q8: NX3008NBKW; SC-70_SOT323_NEX
Q5, Q6: SI4835DDY-T1-E3; SOIC_5DDY-T1-E3_VIS
R1, R2, R3, R4, R5, R6, R7, R8, R9, R10, R11, R12, R13, R14, R15, R16: 2; LTO100_VIS
R17, R18, R19, R20, R23, R24, R25, R26, R33, R34, R35, R36, R37, R38: 10k; R_0603_1608Metric_Pad0.98x0.95mm_HandSolder
R21, R22, R29, R30: 240k; R_0603_1608Metric_Pad0.98x0.95mm_HandSolder
R27, R28: 2M2; R_0603_1608Metric_Pad0.98x0.95mm_HandSolder
R31, R32: 27k; R_0603_1608Metric_Pad0.98x0.95mm_HandSolder
R39, R40: 620k; R_0603_1608Metric_Pad0.98x0.95mm_HandSolder
RV1, RV2, RV3, RV4: 20k; Potentiometer_Bourns_3296Y_Vertical
U1, U2: TLV1702; DGK8_TEX-M
U3, U4: LM35-NEB; TO-220-3_Vertical

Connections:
+12V: C1.2, C2.2, C5.2, C6.2, C7.1, D1.1, D2.1, D3.1, D4.1, J4.1, K1.4, K2.2, K3.4, K4.2, Q5.1 (S), Q5.2 (S), Q5.3 (S), Q6.1 (S), Q6.2 (S), Q6.3 (S), R21.2, R22.2, R23.2, R24.2, R29.2, R30.2, R31.2, R32.2, U1.8 (V+), U2.8 (V+), U3.1 (+V_{S}), U4.1 (+V_{S})
/Fan: J3.1, Q5.5 (D), Q5.6 (D), Q5.7 (D), Q5.8 (D), Q6.5 (D), Q6.6 (D), Q6.7 (D), Q6.8 (D)
/Load_Select: J7.4, Q1.1 (G), Q3.1 (G), R17.1, R19.1
/Mute: J7.3, Q2.1 (G), Q4.1 (G), R18.1, R20.1
/Temp_Control: D2.2, D4.2, K2.4, K4.4, Q2.3 (D), Q4.3 (D), Q7.3 (D), Q8.3 (D)
/Temp_Control_Status_Left: J7.2, Q7.1 (G), R31.1, R35.2, R39.1, U1.1
/Temp_Control_Status_Right: J7.6, Q8.1 (G), R32.1, R36.2, R40.1, U2.1
/Temp_meas1: C3.2, J7.1, R27.2, R33.2, R39.2, U1.3 (+), U1.5 (+)
/Temp_meas2: C4.2, J7.5, R28.2, R34.2, R40.2, U2.3 (+), U2.5 (+)
GND: C1.1, C2.1, C3.1, C4.1, C5.1, C6.1, C7.2, J1.2 (Ext), J2.2 (Ext), J3.2, J4.2, J5.1, J5.2, J6.3, J6.4, K1.3, K3.3, Q1.2 (S), Q2.2 (S), Q3.2 (S), Q4.2 (S), Q7.2 (S), Q8.2 (S), R9.1, R13.1, R17.2, R18.2, R19.2, R20.2, R25.1, R26.1, R35.1, R36.1, R37.1, R38.1, U1.4 (V-), U2.4 (V-), U3.2 (GND), U4.2 (GND)
Left_Plus: J1.1 (In), J5.3, J5.4, K2.5
unnamed: K1.1, R1.1
unnamed: K2.3, R4.2, R12.2
unnamed: K3.1, R5.1
unnamed: K4.3, R8.2, R16.2
unnamed: D1.2, K1.2, Q1.3 (D)
unnamed: D3.2, K3.2, Q3.3 (D)
unnamed: Q5.4 (G), R23.1, R27.1, U1.7
unnamed: Q6.4 (G), R24.1, R28.1, U2.7
unnamed: R1.2, R2.1
unnamed: R2.2, R3.1
unnamed: R3.2, R4.1
unnamed: R5.2, R6.1
unnamed: R6.2, R7.1
unnamed: R7.2, R8.1
unnamed: R9.2, R10.1
unnamed: R10.2, R11.1
unnamed: R11.2, R12.1
unnamed: R13.2, R14.1
unnamed: R14.2, R15.1
unnamed: R15.2, R16.1
unnamed: R21.1, RV1.1
unnamed: R22.1, RV2.1
unnamed: R25.2, RV1.3
unnamed: R26.2, RV2.3
unnamed: R29.1, RV3.1
unnamed: R30.1, RV4.1
unnamed: R37.2, RV3.3
unnamed: R38.2, RV4.3
unnamed: RV3.2, U1.2 (-)
unnamed: RV1.2, U1.6 (-)
unnamed: RV4.2, U2.2 (-)
unnamed: RV2.2, U2.6 (-)
unnamed: R33.1, U3.3 (V_{OUT})
unnamed: R34.1, U4.3 (V_{OUT})
Right_Plus: J2.1 (In), J6.1, J6.2, K4.5

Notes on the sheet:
Right Channel
Connectors & Supplies
Resistor Bank
Left Channel
Temp Control

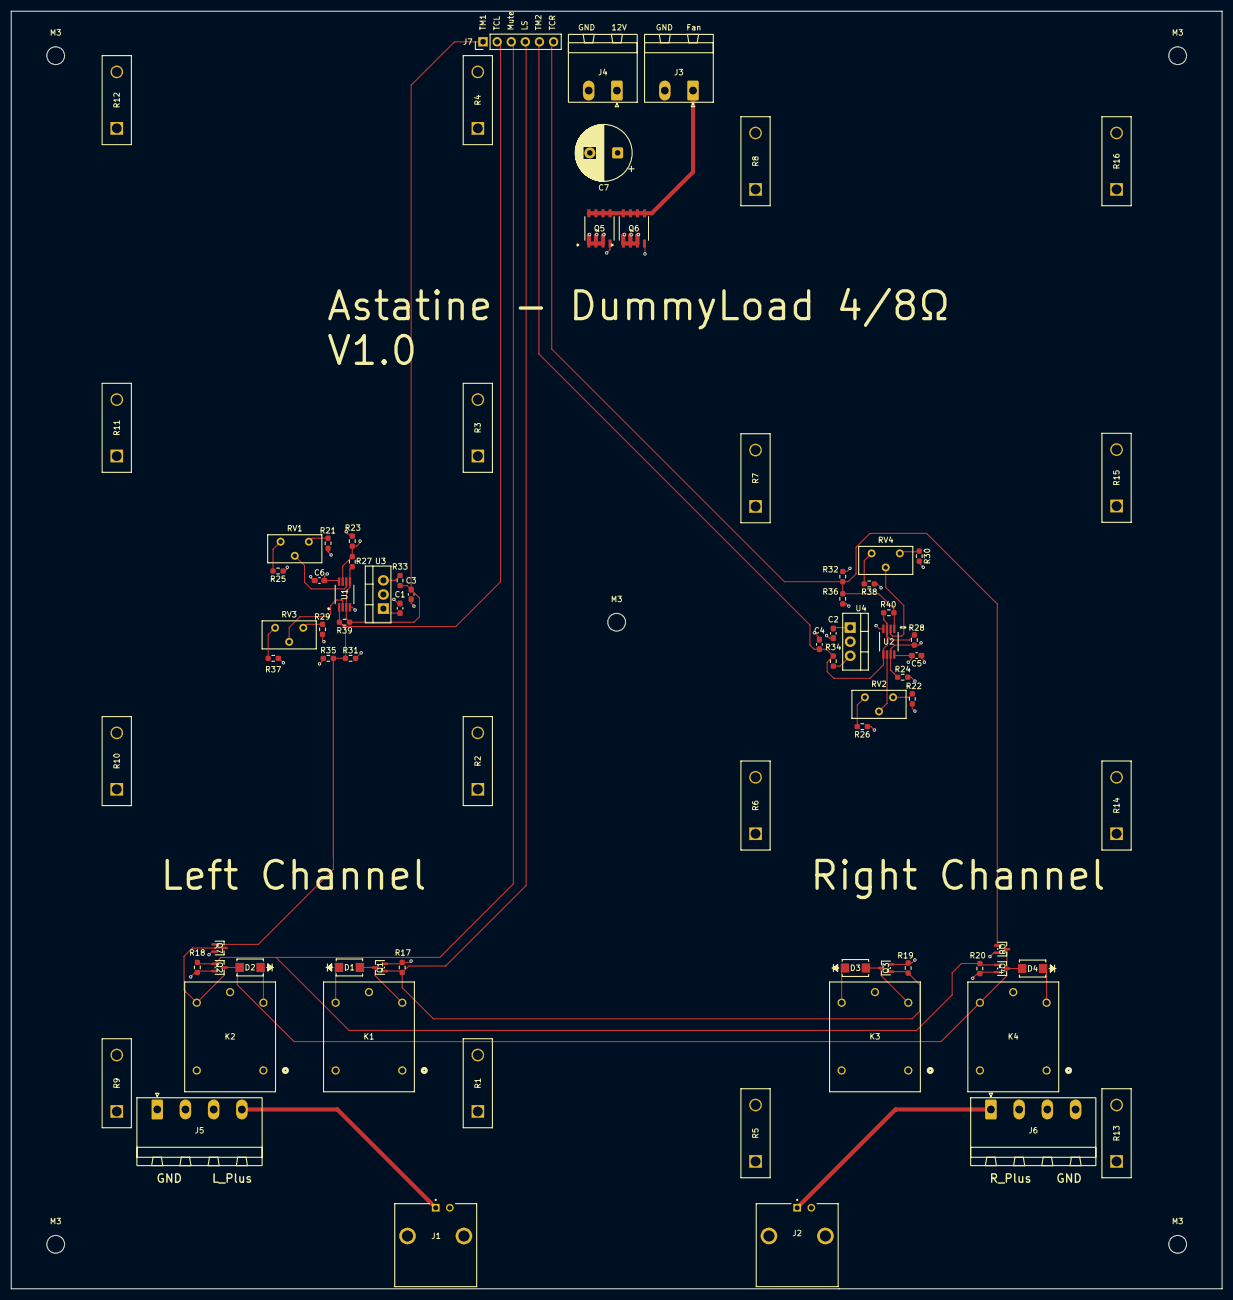
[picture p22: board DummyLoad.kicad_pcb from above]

Board: 4 copper layers, 218.0 x 230.0 mm, 83 parts (0 on the bottom side), 46 nets.

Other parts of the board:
M3, M3#2, M3#3, M3#4, M3#5: MountingHole_3.2mm_M3

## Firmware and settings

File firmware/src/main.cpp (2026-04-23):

#include <Arduino.h>
#include <DMAChannel.h>
#include <math.h>
#include <string.h>

// ═══════════════════════════════════════════════════════════════════════════
// Teensy 4.1 — PCM4222 ADC receiver + PCM5102 DAC transmitter
//
// ADC (receiver, SAI1 RX):
//   Pin 8  = SAI1_RX_DATA0  ← PCM4222 data out
//   Pin 20 = SAI1_RX_SYNC   ← LRCK
//   Pin 21 = SAI1_RX_BCLK   ← BCLK
//
// DAC (transmitter, SAI1 TX):
//   Pin 7  = SAI1_TX_DATA0  → PCM5102 DIN
//   Pin 20 = SAI1_TX_SYNC   ← shared LRCK
//   Pin 21 = SAI1_TX_BCLK   ← shared BCLK
//
// IMPORTANT:
//   This build does NOT decimate.
//   Actual streamed sample rate is SOURCE_FS = 192000 Hz.
//   Therefore Python/debug tools must use FS = 192000 unless you add
//   decimation in firmware.
//
// USB diagnostic stream modes:
//   0 = normal   -> send L,R
//   1 = dup L    -> send L,L
//   2 = dup R    -> send R,R
//   3 = swap     -> send R,L
//
// Start with:
//   #define USB_STREAM_MODE 1
//
// If both Python plots then become identical, the GUI/parser is fine and the
// real problem is upstream of USB (ADC right input / routing / firmware RX).
// ═══════════════════════════════════════════════════════════════════════════

static constexpr uint32_t PACKET_MAGIC = 0x30445541u;

// ── ADC configuration ──────────────────────────────────────────────────────
#define SOURCE_FS       192000
#define BLOCK_PAIRS     512
#define HALF_WORDS      (BLOCK_PAIRS * 2)   // 1024 int32 words = 512 stereo pairs
#define TOTAL_WORDS     (HALF_WORDS * 2)
#define WARMUP_HALVES   24

// ── DAC sine test configuration ────────────────────────────────────────────
#define SINE_FREQ_HZ       1000
#define TARGET_VPP         1.0f
#define PCM5102_PEAK_V     2.9698f
#define DAC_SHIFT_BITS     8
#define USE_BCP            1   // must be 1 in your working DAC build

#define SAMPLES_PER_PERIOD (SOURCE_FS / SINE_FREQ_HZ)
#define SINE_PERIODS       10
#define SINE_BUF_PAIRS     (SAMPLES_PER_PERIOD * SINE_PERIODS)
#define SINE_BUF_WORDS     (SINE_BUF_PAIRS * 2)

#define USB_STREAM_MODE    1   // 0=normal, 1=dup L, 2=dup R, 3=swap

static constexpr float TWO_PI_F = 6.2831853071795864769f;
static const int32_t DAC_FS_24 = 8388607;

static const int32_t SINE_AMPLITUDE_24 =
    (int32_t)((TARGET_VPP / 2.0f / PCM5102_PEAK_V) * (float)DAC_FS_24);

struct PacketHeader {
    uint32_t magic;
    uint32_t words;
    uint32_t sequence;
};

// ── Buffers ────────────────────────────────────────────────────────────────
DMAMEM static int32_t dma_rx_buf[TOTAL_WORDS];
static  int32_t safe_buf[2][HALF_WORDS];
DMAMEM static int32_t sine_buf[SINE_BUF_WORDS];

// USB diagnostic mapping buffer
static int32_t usb_tx_buf[HALF_WORDS];

static DMAChannel dma_rx;
static DMAChannel dma_tx;

volatile uint8_t  ready_mask  = 0;
volatile uint32_t overruns    = 0;
volatile uint32_t halves_seen = 0;
static   uint32_t packet_seq  = 0;


// ───────────────────────────────────────────────────────────────────────────
// Generate DAC sine: 24-bit sample left-justified into 32-bit slot
// ───────────────────────────────────────────────────────────────────────────
static void generate_sine_buf() {
    for (int i = 0; i < SINE_BUF_PAIRS; i++) {
        float phase = TWO_PI_F * (float)i / (float)SAMPLES_PER_PERIOD;
        float s     = sinf(phase);

        int32_t samp24 = (int32_t)((float)SINE_AMPLITUDE_24 * s);

        if (samp24 >  8388607) samp24 =  8388607;
        if (samp24 < -8388608) samp24 = -8388608;

        int32_t word = samp24 << DAC_SHIFT_BITS;

        sine_buf[2 * i + 0] = word;  // L
        sine_buf[2 * i + 1] = word;  // R
    }

    arm_dcache_flush(sine_buf, sizeof(sine_buf));
}


// ───────────────────────────────────────────────────────────────────────────
// ADC RX ISR
// ───────────────────────────────────────────────────────────────────────────
void FASTRUN dma_rx_isr() {
    const uint32_t daddr = (uint32_t)dma_rx.TCD->DADDR;
    dma_rx.clearInterrupt();

    uint8_t completed;
    const int32_t* src;

    if (daddr < ((uint32_t)dma_rx_buf + sizeof(dma_rx_buf) / 2)) {
        completed = 1;
        src       = dma_rx_buf + HALF_WORDS;
    } else {
        completed = 0;
        src       = dma_rx_buf;
    }

    const uint8_t bit = (1u << completed);

    if (ready_mask & bit) {
        overruns++;
    } else {
        arm_dcache_delete((void*)src, HALF_WORDS * sizeof(int32_t));
        memcpy(safe_buf[completed], src, HALF_WORDS * sizeof(int32_t));
        ready_mask |= bit;
    }

    asm volatile("dsb");
}


// ───────────────────────────────────────────────────────────────────────────
// SAI1 configuration
// RX: slave from PCM4222
// TX: synchronous to RX
// ───────────────────────────────────────────────────────────────────────────
static void sai1_config() {
    CCM_CCGR5 |= CCM_CCGR5_SAI1(CCM_CCGR_ON);

    // ── RX reset ──────────────────────────────────────────────────────────
    I2S1_RCSR = (1 << 24);
    delayMicroseconds(10);
    I2S1_RCSR = 0;
    delayMicroseconds(10);

    I2S1_RCR1 = I2S_RCR1_RFW(3);
    I2S1_RCR2 = I2S_RCR2_BCP;
    I2S1_RCR3 = I2S_RCR3_RCE;
    I2S1_RCR4 = I2S_RCR4_FSP | I2S_RCR4_FSE | I2S_RCR4_MF
              | I2S_RCR4_SYWD(31) | I2S_RCR4_FRSZ(1);
    I2S1_RCR5 = I2S_RCR5_WNW(31) | I2S_RCR5_W0W(31) | I2S_RCR5_FBT(31);

    // ── TX reset ──────────────────────────────────────────────────────────
    I2S1_TCSR = (1 << 24);
    delayMicroseconds(10);
    I2S1_TCSR = 0;
    delayMicroseconds(10);

    I2S1_TCR1 = I2S_TCR1_RFW(3);
    I2S1_TCR2 = I2S_TCR2_SYNC(1) | I2S_TCR2_BCP;
    I2S1_TCR3 = I2S_TCR3_TCE;
    I2S1_TCR4 = I2S_TCR4_FSP | I2S_TCR4_FSE | I2S_TCR4_MF
              | I2S_TCR4_SYWD(31) | I2S_TCR4_FRSZ(1);
    I2S1_TCR5 = I2S_TCR5_WNW(31) | I2S_TCR5_W0W(31) | I2S_TCR5_FBT(31);

    // ── Pin mux ───────────────────────────────────────────────────────────
    CORE_PIN8_CONFIG  = 3;   // SAI1_RX_DATA0
    CORE_PIN20_CONFIG = 3;   // SAI1_RX_SYNC / TX_SYNC
    CORE_PIN21_CONFIG = 3;   // SAI1_RX_BCLK / TX_BCLK
    CORE_PIN7_CONFIG  = 3;   // SAI1_TX_DATA0

    IOMUXC_SAI1_RX_DATA0_SELECT_INPUT = 2;
    IOMUXC_SAI1_RX_BCLK_SELECT_INPUT  = 1;
    IOMUXC_SAI1_RX_SYNC_SELECT_INPUT  = 1;
}


// ───────────────────────────────────────────────────────────────────────────
// DMA configuration
// ───────────────────────────────────────────────────────────────────────────
static void dma_config() {
    // ── RX DMA: SAI1_RDR0 → dma_rx_buf ────────────────────────────────────
    dma_rx.begin(true);
    dma_rx.TCD->SADDR    = &I2S1_RDR0;
    dma_rx.TCD->SOFF     = 0;
    dma_rx.TCD->SLAST    = 0;
    dma_rx.TCD->ATTR     = DMA_TCD_ATTR_SSIZE(2) | DMA_TCD_ATTR_DSIZE(2);
    dma_rx.TCD->NBYTES   = 4;
    dma_rx.TCD->DADDR    = dma_rx_buf;
    dma_rx.TCD->DOFF     = 4;
    dma_rx.TCD->CITER    = TOTAL_WORDS;
    dma_rx.TCD->BITER    = TOTAL_WORDS;
    dma_rx.TCD->DLASTSGA = -(int32_t)sizeof(dma_rx_buf);
    dma_rx.TCD->CSR      = DMA_TCD_CSR_INTHALF | DMA_TCD_CSR_INTMAJOR;
    dma_rx.attachInterrupt(dma_rx_isr);
    dma_rx.triggerAtHardwareEvent(DMAMUX_SOURCE_SAI1_RX);

    // ── TX DMA: sine_buf → SAI1_TDR0 ──────────────────────────────────────
    dma_tx.begin(true);
    dma_tx.TCD->SADDR    = sine_buf;
    dma_tx.TCD->SOFF     = 4;
    dma_tx.TCD->SLAST    = -(int32_t)sizeof(sine_buf);
    dma_tx.TCD->ATTR     = DMA_TCD_ATTR_SSIZE(2) | DMA_TCD_ATTR_DSIZE(2);
    dma_tx.TCD->NBYTES   = 4;
    dma_tx.TCD->DADDR    = &I2S1_TDR0;
    dma_tx.TCD->DOFF     = 0;
    dma_tx.TCD->DLASTSGA = 0;
    dma_tx.TCD->CITER    = SINE_BUF_WORDS;
    dma_tx.TCD->BITER    = SINE_BUF_WORDS;
    dma_tx.TCD->CSR      = 0;
    dma_tx.triggerAtHardwareEvent(DMAMUX_SOURCE_SAI1_TX);
}


// ───────────────────────────────────────────────────────────────────────────
// Prepare USB packet payload from captured half-buffer
// src is interleaved stereo: L,R,L,R,...
// ───────────────────────────────────────────────────────────────────────────
static void map_half_for_usb(const int32_t* src, int32_t* dst) {
    if (USB_STREAM_MODE == 0) {
        memcpy(dst, src, HALF_WORDS * sizeof(int32_t));
        return;
    }

    const int pairs = HALF_WORDS / 2;

    for (int i = 0; i < pairs; i++) {
        const int32_t l = src[2 * i + 0];
        const int32_t r = src[2 * i + 1];

        if (USB_STREAM_MODE == 1) {
            dst[2 * i + 0] = l;  // L
            dst[2 * i + 1] = l;  // L
        } else if (USB_STREAM_MODE == 2) {
            dst[2 * i + 0] = r;  // R
            dst[2 * i + 1] = r;  // R
        } else { // USB_STREAM_MODE == 3
            dst[2 * i + 0] = r;  // swap
            dst[2 * i + 1] = l;
        }
    }
}


// ───────────────────────────────────────────────────────────────────────────
// Send one half-buffer over USB
// ───────────────────────────────────────────────────────────────────────────
static void send_half(int half) {
    const int32_t* src = safe_buf[half];
    map_half_for_usb(src, usb_tx_buf);

    PacketHeader hdr;
    hdr.magic    = PACKET_MAGIC;
    hdr.words    = HALF_WORDS;
    hdr.sequence = packet_seq++;

    Serial.write(reinterpret_cast<const uint8_t*>(&hdr), sizeof(hdr));
    Serial.write(reinterpret_cast<const uint8_t*>(usb_tx_buf), HALF_WORDS * sizeof(int32_t));
}


// ───────────────────────────────────────────────────────────────────────────
// Setup
// ───────────────────────────────────────────────────────────────────────────
void setup() {
    Serial.begin(115200);
    while (!Serial && millis() < 10000) {}
    delay(200);

    pinMode(LED_BUILTIN, OUTPUT);
    digitalWrite(LED_BUILTIN, LOW);

    generate_sine_buf();
    memset(dma_rx_buf, 0, sizeof(dma_rx_buf));
    memset(safe_buf,   0, sizeof(safe_buf));
    memset(usb_tx_buf, 0, sizeof(usb_tx_buf));

    sai1_config();
    dma_config();

    dma_rx.enable();
    dma_tx.enable();

    I2S1_RCSR |= I2S_RCSR_RE | I2S_RCSR_BCE | I2S_RCSR_FRDE;
    I2S1_TCSR |= I2S_TCSR_TE | I2S_TCSR_FRDE;

    Serial.println("=== ADC/DAC USB DIAGNOSTIC ===");
    Serial.printf("SOURCE_FS             = %d Hz\n", SOURCE_FS);
    Serial.printf("BLOCK_PAIRS           = %d\n", BLOCK_PAIRS);
    Serial.printf("HALF_WORDS            = %d\n", HALF_WORDS);
    Serial.printf("USB_STREAM_MODE       = %d\n", USB_STREAM_MODE);
    Serial.printf("Expected packet rate  = %.1f pkt/s\n", (float)SOURCE_FS / (float)BLOCK_PAIRS);
    Serial.printf("DAC sine              = %d Hz\n", SINE_FREQ_HZ);
    Serial.printf("USE_BCP               = %d\n", USE_BCP);
    Serial.println("Modes: 0=normal, 1=dupL, 2=dupR, 3=swap");
    Serial.println("==============================");
}


// ───────────────────────────────────────────────────────────────────────────
// Loop
// ───────────────────────────────────────────────────────────────────────────
void loop() {
    static uint32_t t_led  = 0;
    static uint32_t t_diag = 0;

    // Heartbeat LED
    if (millis() - t_led > 500) {
        t_led = millis();
        digitalWrite(LED_BUILTIN, !digitalRead(LED_BUILTIN));
    }

    // Send ready half-buffers over USB
    if (ready_mask & 1u) {
        noInterrupts();
        ready_mask &= ~1u;
        interrupts();

        if (halves_seen >= WARMUP_HALVES) {
            send_half(0);
        }
        halves_seen++;
    }

    if (ready_mask & 2u) {
        noInterrupts();
        ready_mask &= ~2u;
        interrupts();

        if (halves_seen >= WARMUP_HALVES) {
            send_half(1);
        }
        halves_seen++;
    }

    // Periodic diagnostics
    if (millis() - t_diag > 5000) {
        t_diag = millis();

        Serial.println("=== LIVE DIAG ===");
        Serial.printf("halves_seen          = %lu\n", (unsigned long)halves_seen);
        Serial.printf("packet_seq           = %lu\n", (unsigned long)packet_seq);
        Serial.printf("overruns             = %lu\n", (unsigned long)overruns);
        Serial.printf("USB_STREAM_MODE      = %d\n", USB_STREAM_MODE);
        Serial.println("=================");
    }
}

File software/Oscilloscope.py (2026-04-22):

"""
Audio Analyzer — Oscilloscope Mode
==================================

Updated version:
- Better readable UI (dark text on light controls)
- Added parse mode selector:
    * interleaved  -> L,R,L,R,...
    * swap         -> R,L,R,L,...
    * mono_left    -> duplicate left into both plots
    * mono_right   -> duplicate right into both plots
- Added L/R correlation in status line
- Added simple warning if one channel is much smaller than the other
"""

import sys
import time
import struct
import threading
from dataclasses import dataclass
from typing import Optional

import numpy as np
import serial
import serial.tools.list_ports
import pyqtgraph as pg
from pyqtgraph.Qt import QtCore, QtWidgets


# =============================================================================
# Teensy / protocol
# =============================================================================
PORT = None
BAUD = 2_000_000
FS   = 192_000

HEADER      = struct.Struct("<III")
MAGIC       = 0x30445541
MAGIC_BYTES = struct.pack("<I", MAGIC)
MAX_WORDS   = 65536

# Default parser mode
DEFAULT_PARSE_MODE = "interleaved"   # interleaved, swap, mono_left, mono_right


# =============================================================================
# Ring buffer
# =============================================================================
RING_SECS = 1.0
RING_SIZE = int(FS * RING_SECS)

_ring_l    = np.zeros(RING_SIZE, dtype=np.int32)
_ring_r    = np.zeros(RING_SIZE, dtype=np.int32)
_write_ptr = 0
_ptr_lock  = threading.Lock()

packet_drops = 0
stop_event   = threading.Event()


def ring_write(left: np.ndarray, right: np.ndarray):
    global _write_ptr

    n = len(left)
    ptr = _write_ptr % RING_SIZE
    end = ptr + n

    if end <= RING_SIZE:
        _ring_l[ptr:end] = left
        _ring_r[ptr:end] = right
    else:
        first = RING_SIZE - ptr
        _ring_l[ptr:]       = left[:first]
        _ring_l[:n - first] = left[first:]
        _ring_r[ptr:]       = right[:first]
        _ring_r[:n - first] = right[first:]

    with _ptr_lock:
        _write_ptr += n


def ring_available() -> int:
    return min(_write_ptr, RING_SIZE)


def ring_read_last(n: int):
    with _ptr_lock:
        ptr = _write_ptr

    start = (ptr - n) % RING_SIZE
    if start + n <= RING_SIZE:
        return _ring_l[start:start + n].copy(), _ring_r[start:start + n].copy()

    cut = RING_SIZE - start
    l = np.concatenate([_ring_l[start:], _ring_l[:n - cut]])
    r = np.concatenate([_ring_r[start:], _ring_r[:n - cut]])
    return l, r


# =============================================================================
# Display config
# =============================================================================
REFRESH_MS              = 30
DEFAULT_TIME_WINDOW_MS  = 5.0
PRETRIGGER              = 0.25
SEARCH_WINDOWS          = 4
TRIGGER_HOLDOFF_FRAC    = 0.80
TRIGGER_HYSTERESIS_FRAC = 0.05
SHOW_IN_KCOUNTS         = True
DEFAULT_SMOOTH_SAMPLES  = 1


# =============================================================================
# Helpers
# =============================================================================
def find_port():
    for p in serial.tools.list_ports.comports():
        desc = (p.description or "").lower()
        manu = (p.manufacturer or "").lower() if p.manufacturer else ""
        if "teensy" in desc or "pjrc" in manu:
            return p.device

    ports = list(serial.tools.list_ports.comports())
    if len(ports) == 1:
        return ports[0].device
    return None


def counts_to_display(x: np.ndarray) -> np.ndarray:
    return x.astype(np.float64) / 1000.0 if SHOW_IN_KCOUNTS else x.astype(np.float64)


def display_unit() -> str:
    return "kcounts" if SHOW_IN_KCOUNTS else "counts"


def smooth_signal(x: np.ndarray, n: int) -> np.ndarray:
    if n <= 1:
        return x
    kernel = np.ones(n, dtype=np.float64) / float(n)
    return np.convolve(x, kernel, mode="same")


def estimate_freq(x: np.ndarray, fs: float):
    if len(x) < 32:
        return None

    y = x - np.mean(x)
    if np.max(np.abs(y)) < 10:
        return None

    crossings = np.where((y[:-1] < 0) & (y[1:] >= 0))[0]
    if len(crossings) < 2:
        return None

    periods = np.diff(crossings) / fs
    periods = periods[periods > 0]
    return 1.0 / np.median(periods) if len(periods) else None


def basic_stats(x: np.ndarray, fs: float) -> dict:
    xf = x.astype(np.float64)
    return {
        "mean": float(np.mean(xf)),
        "rms":  float(np.sqrt(np.mean(xf * xf))),
        "vpp":  float(np.ptp(xf)),
        "freq": estimate_freq(xf, fs),
    }


def parse_payload(raw: np.ndarray, mode: str):
    if mode == "interleaved":
        left  = raw[0::2]
        right = raw[1::2]
    elif mode == "swap":
        left  = raw[1::2]
        right = raw[0::2]
    elif mode == "mono_left":
        left  = raw[0::2]
        right = left.copy()
    elif mode == "mono_right":
        right = raw[1::2]
        left  = right.copy()
    else:
        left  = raw[0::2]
        right = raw[1::2]

    n = min(len(left), len(right))
    return left[:n], right[:n]


def find_trigger_start(x, window_samples, pretrigger, level, edge, holdoff):
    n = len(x)
    if n < window_samples + 2:
        return 0, False

    pre        = int(window_samples * pretrigger)
    search_len = min(n, window_samples * SEARCH_WINDOWS)
    search     = x[-search_len:]
    s_len      = len(search)

    sig_range = float(np.ptp(search))
    hyst      = max(sig_range * TRIGGER_HYSTERESIS_FRAC, abs(level) * 0.05 + 1.0)

    if edge == "rising":
        armed    = search < (level - hyst)
        crossing = (search[:-1] < level) & (search[1:] >= level)
        arm_before = np.zeros(s_len - 1, dtype=bool)
        state = False
        for i in range(s_len - 1):
            if armed[i]:
                state = True
            if crossing[i]:
                arm_before[i] = state
                state = False
        cands = np.where(arm_before & crossing)[0] + 1
    else:
        armed    = search > (level + hyst)
        crossing = (search[:-1] > level) & (search[1:] <= level)
        arm_before = np.zeros(s_len - 1, dtype=bool)
        state = False
        for i in range(s_len - 1):
            if armed[i]:
                state = True
            if crossing[i]:
                arm_before[i] = state
                state = False
        cands = np.where(arm_before & crossing)[0] + 1

    if len(cands) == 0:
        return n - window_samples, False

    for idx in reversed(cands):
        abs_idx = (n - search_len) + idx
        start   = abs_idx - pre
        end     = start + window_samples
        if start >= 0 and end <= n:
            if abs_idx + holdoff > n - pre:
                continue
            return start, True

    return n - window_samples, False
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

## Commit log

2026-03-04 Initial commit: PlatformIO Teensy 4.1 hello world
    [Audio_analyser.PrjPcb, Schlib1.SchLib, Test_setup.SchDoc]
2026-03-07 Add I2S slave firmware and Python serial multimeter
    - firmware: Teensy 4.1 I2S slave RX, CSV streaming til PC
    - software: RMS multimeter med dBFS visning og auto COM-detect
2026-04-17 Changed from Altium to KiCad do to licens issues, and have designed 1st revision of the DummyLoad
    [Audio_analyser.PrjPcb, DummyLoad.kicad_pcb, DummyLoad.kicad_sch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]
2026-04-22 Version 1.0 of the DummyLoad
    [DummyLoad-B_Cu.gbr, DummyLoad-B_Mask.gbr, DummyLoad-B_Paste.gbr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]
2026-04-22 Updated python tools for testing the connection between the pc, teensy and ADC
2026-04-23 Updated firmware for teensy, with DAC setup
2026-05-15 Version 1.0 of the audio analyzer and fix embedded repo warnings
    [ADC.kicad_sch, ADC_Clock_Control_Config.kicad_sch, ADC_Core_PCM4222.kicad_sch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]
